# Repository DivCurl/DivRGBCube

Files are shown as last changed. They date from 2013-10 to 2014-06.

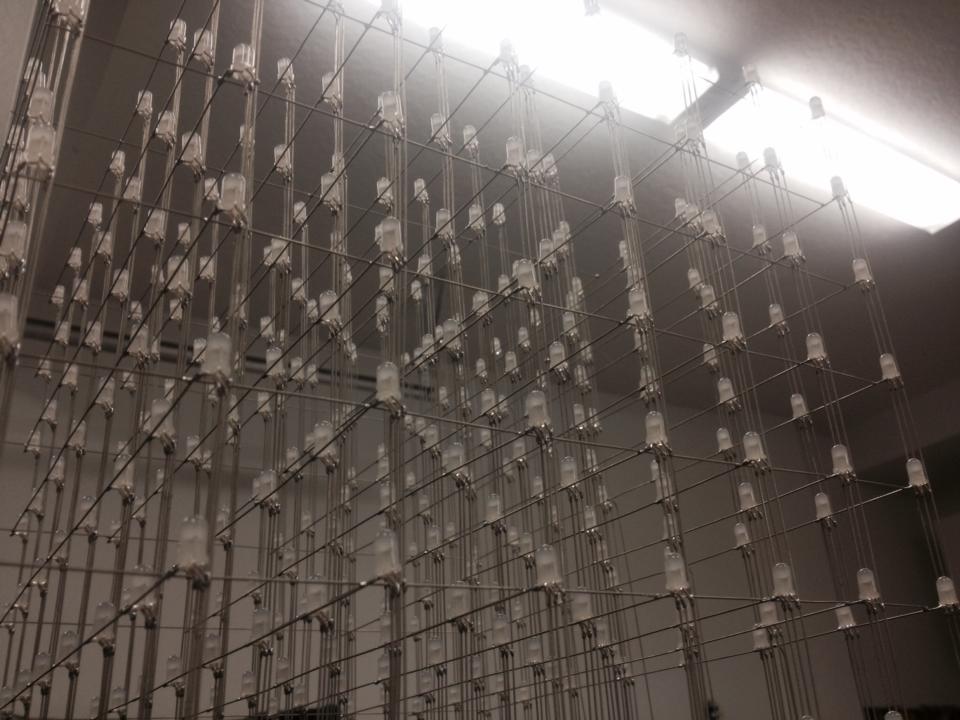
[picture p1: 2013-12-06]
Pics/Post-1.jpg

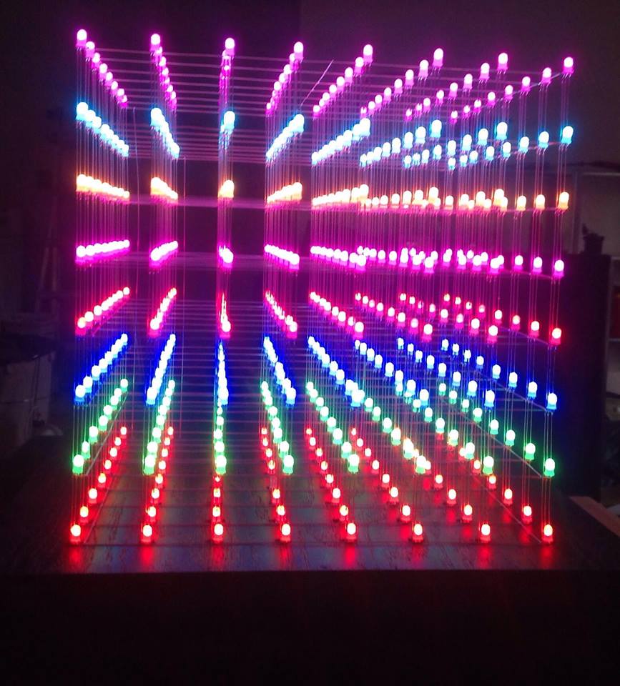
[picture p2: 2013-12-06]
Pics/Cube-4.jpg

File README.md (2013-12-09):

DivRGBCube
==========

8x8x8 RGB Cube Project Resources

Aiming to supply other makers with resources to build my 8^3 RGB LED cube design. Some of the design choices were inspired by others and have been credited appropriately, but this is mostly my own custom design and built completely from scratch. I've provided a custom board layout designed in eagle, which has some minor flaws (nothing I would consider a fault however) which I've noted accordingly, but otherwise I'm using the as-designed board and have yet to encounter a problem. I've also written the software to satisfy my own needs and knowledge level.

All code is written in standard C using Microchip's MPLAB X IDE. I am not a seasoned C veteran by any means so please feel free to suggest alternative or more efficient ways of doing things, I am sure there are plenty of areas which could use some improving and optimization. All build files are included in addition to the source.

The target microcontroller platform is a PIC32. There should be only minimal hassles to port the code to other platforms - I believe the only major portion that would require rewrites would be the interrupt handlers and of course the I/O pin definitions and latch functions (for example the TRIS and LATx macros). The PIC32 was chosen due to its fast speed given that I'm using shift registers for each LED cathode and handling the color fading in software using BCM (aka BAM) thus requiring a very fast refresh rate to avoid flickering artifacts and to maintain a good frame rate. Credits to Nick Schulze of www.hownottoengineer.com for this particular design inspiration. The implementation of software BCM was a fun challenge.

This is still a work in progress project so I'm constantly adding new features so stay tuned for new builds and updates.

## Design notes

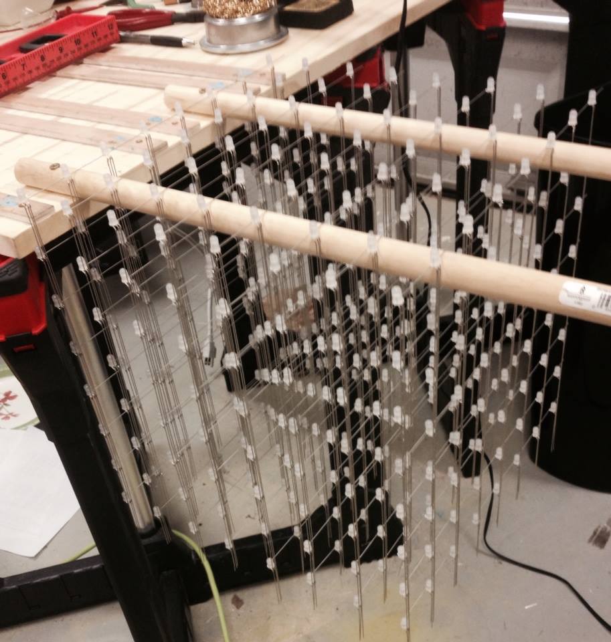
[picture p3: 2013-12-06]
Pics/Cube-1.jpg

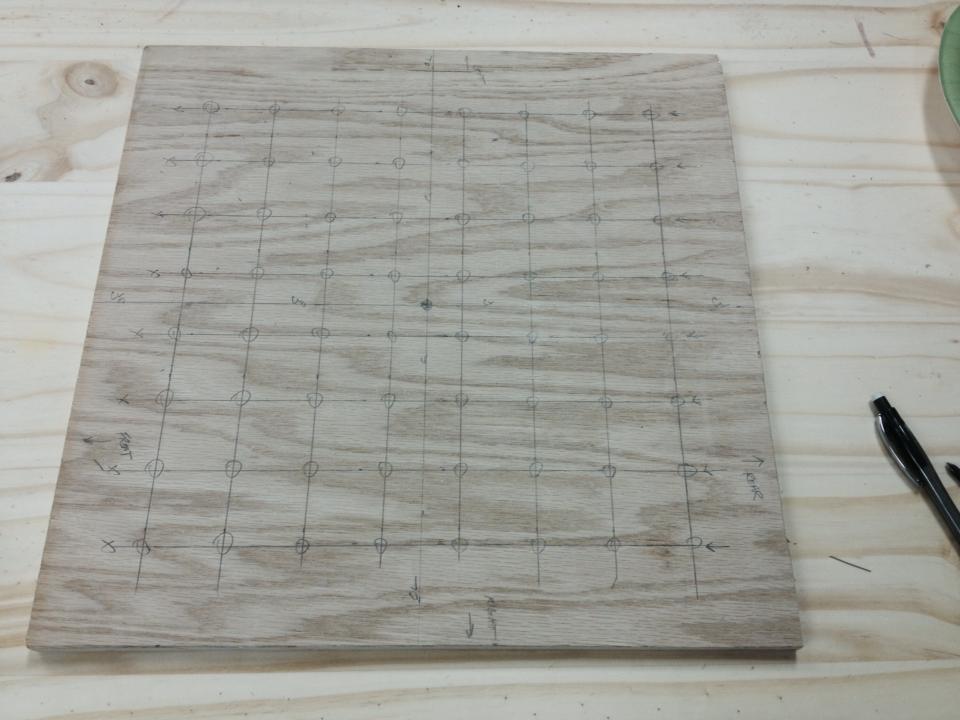
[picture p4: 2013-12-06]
Pics/Box-1.jpg

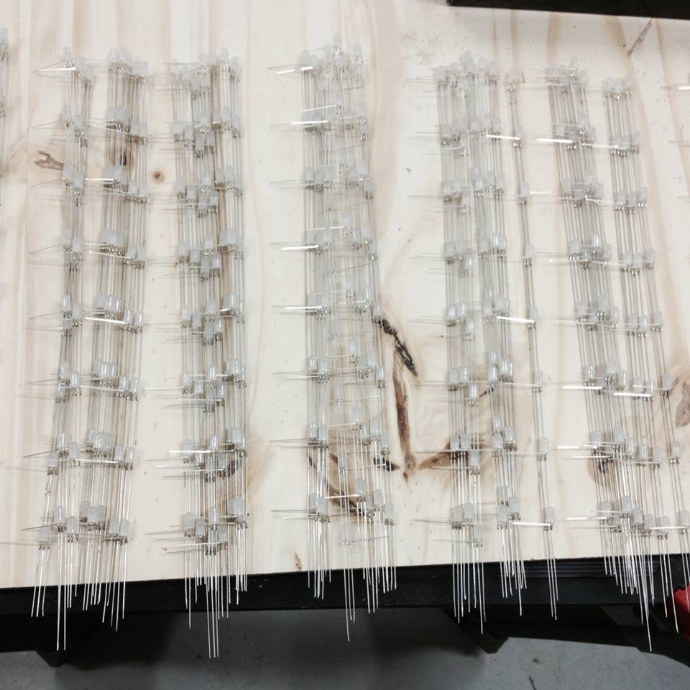
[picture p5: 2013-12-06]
Pics/Jig-7.jpg

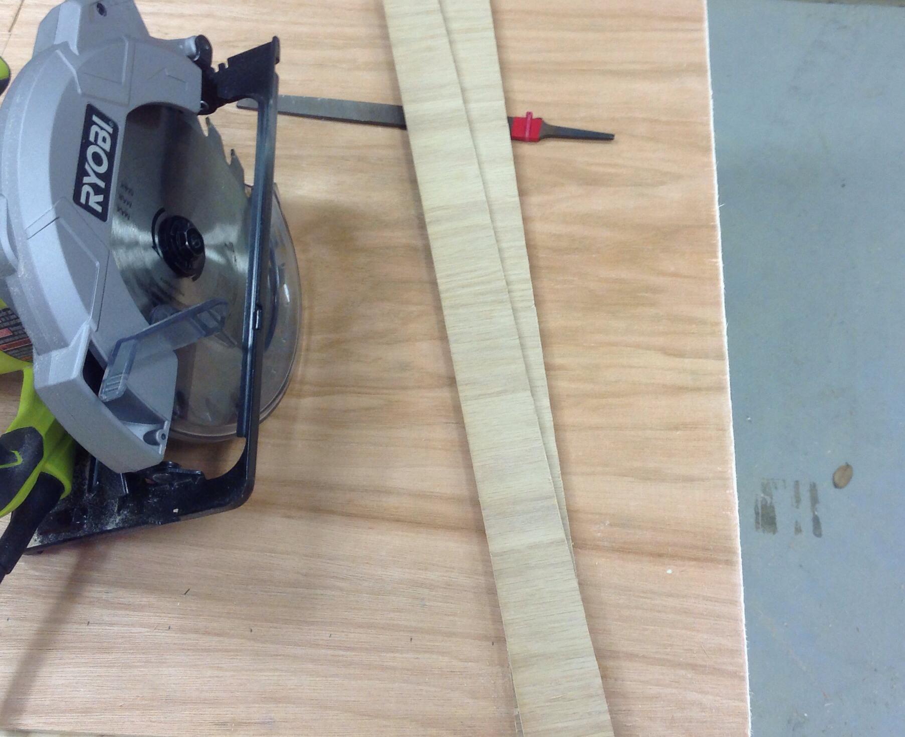
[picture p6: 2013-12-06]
Pics/Jig-1.jpg

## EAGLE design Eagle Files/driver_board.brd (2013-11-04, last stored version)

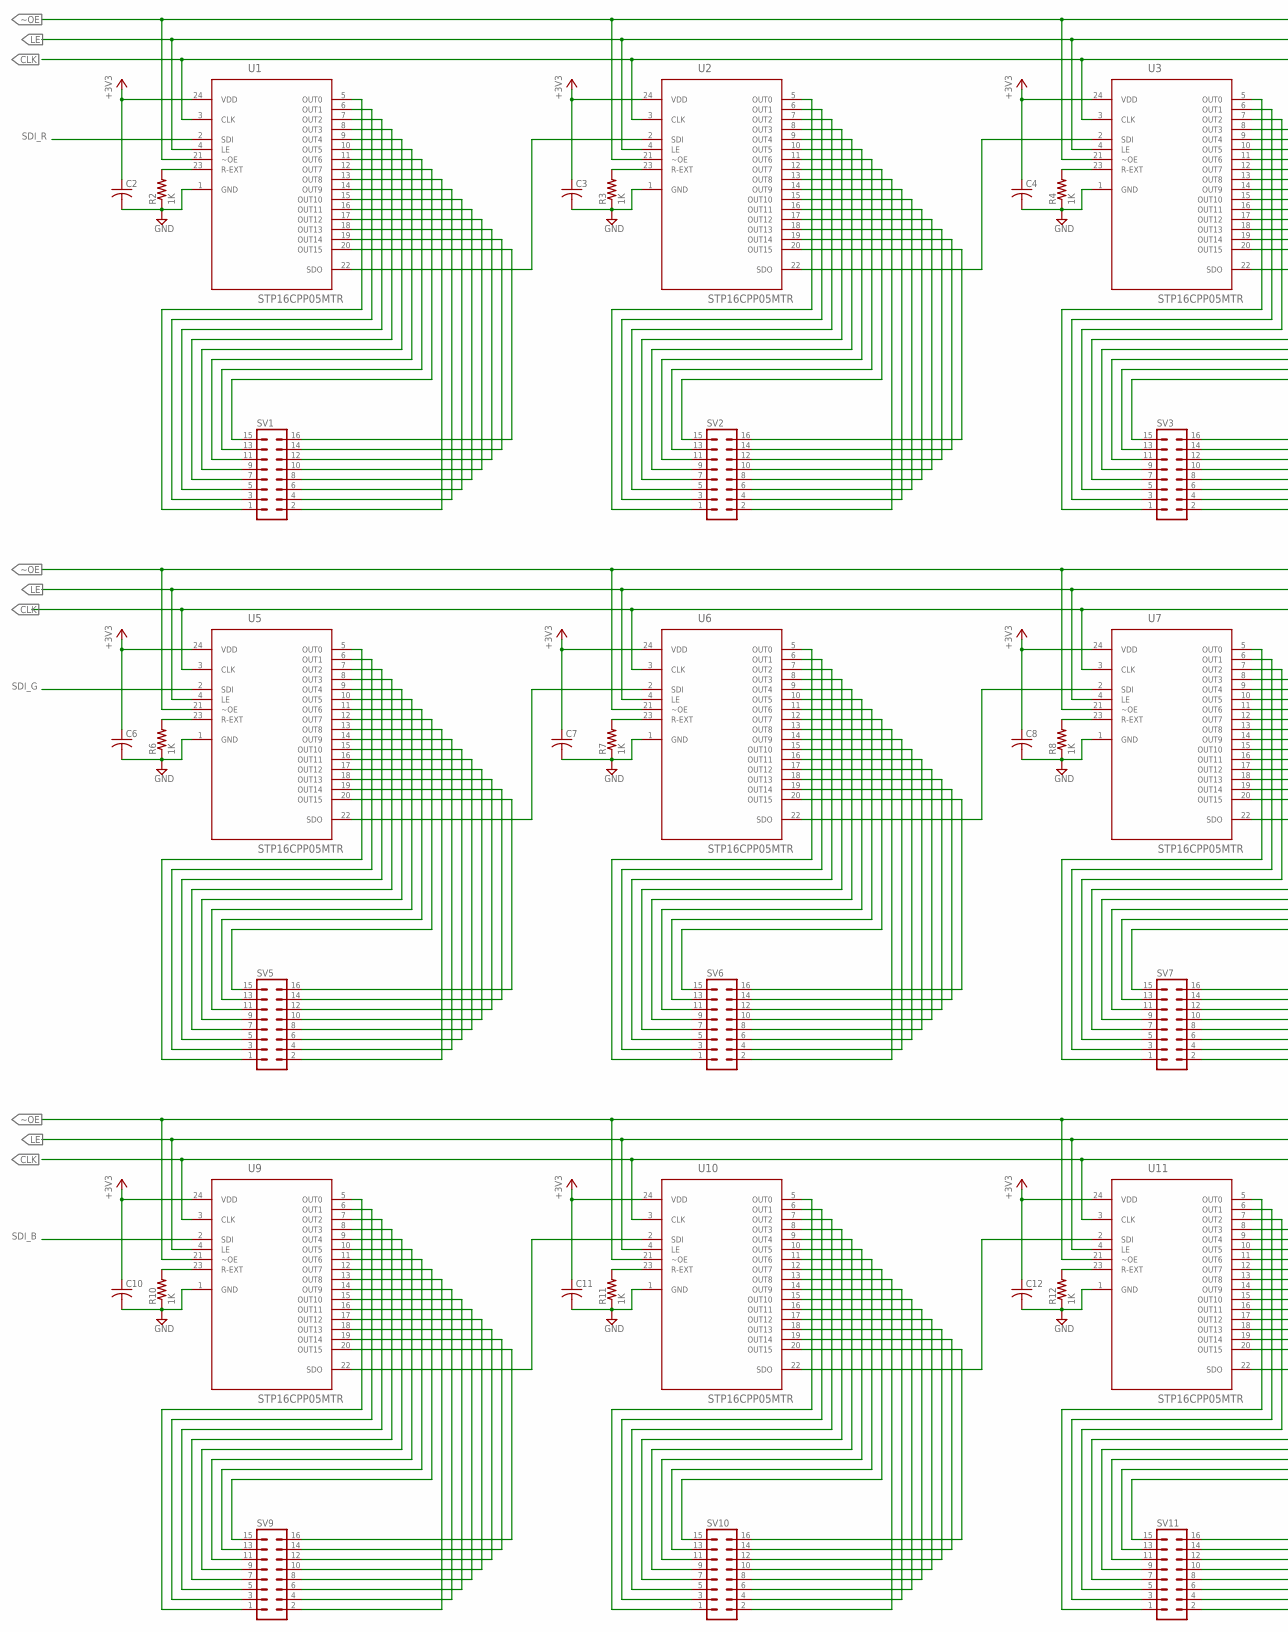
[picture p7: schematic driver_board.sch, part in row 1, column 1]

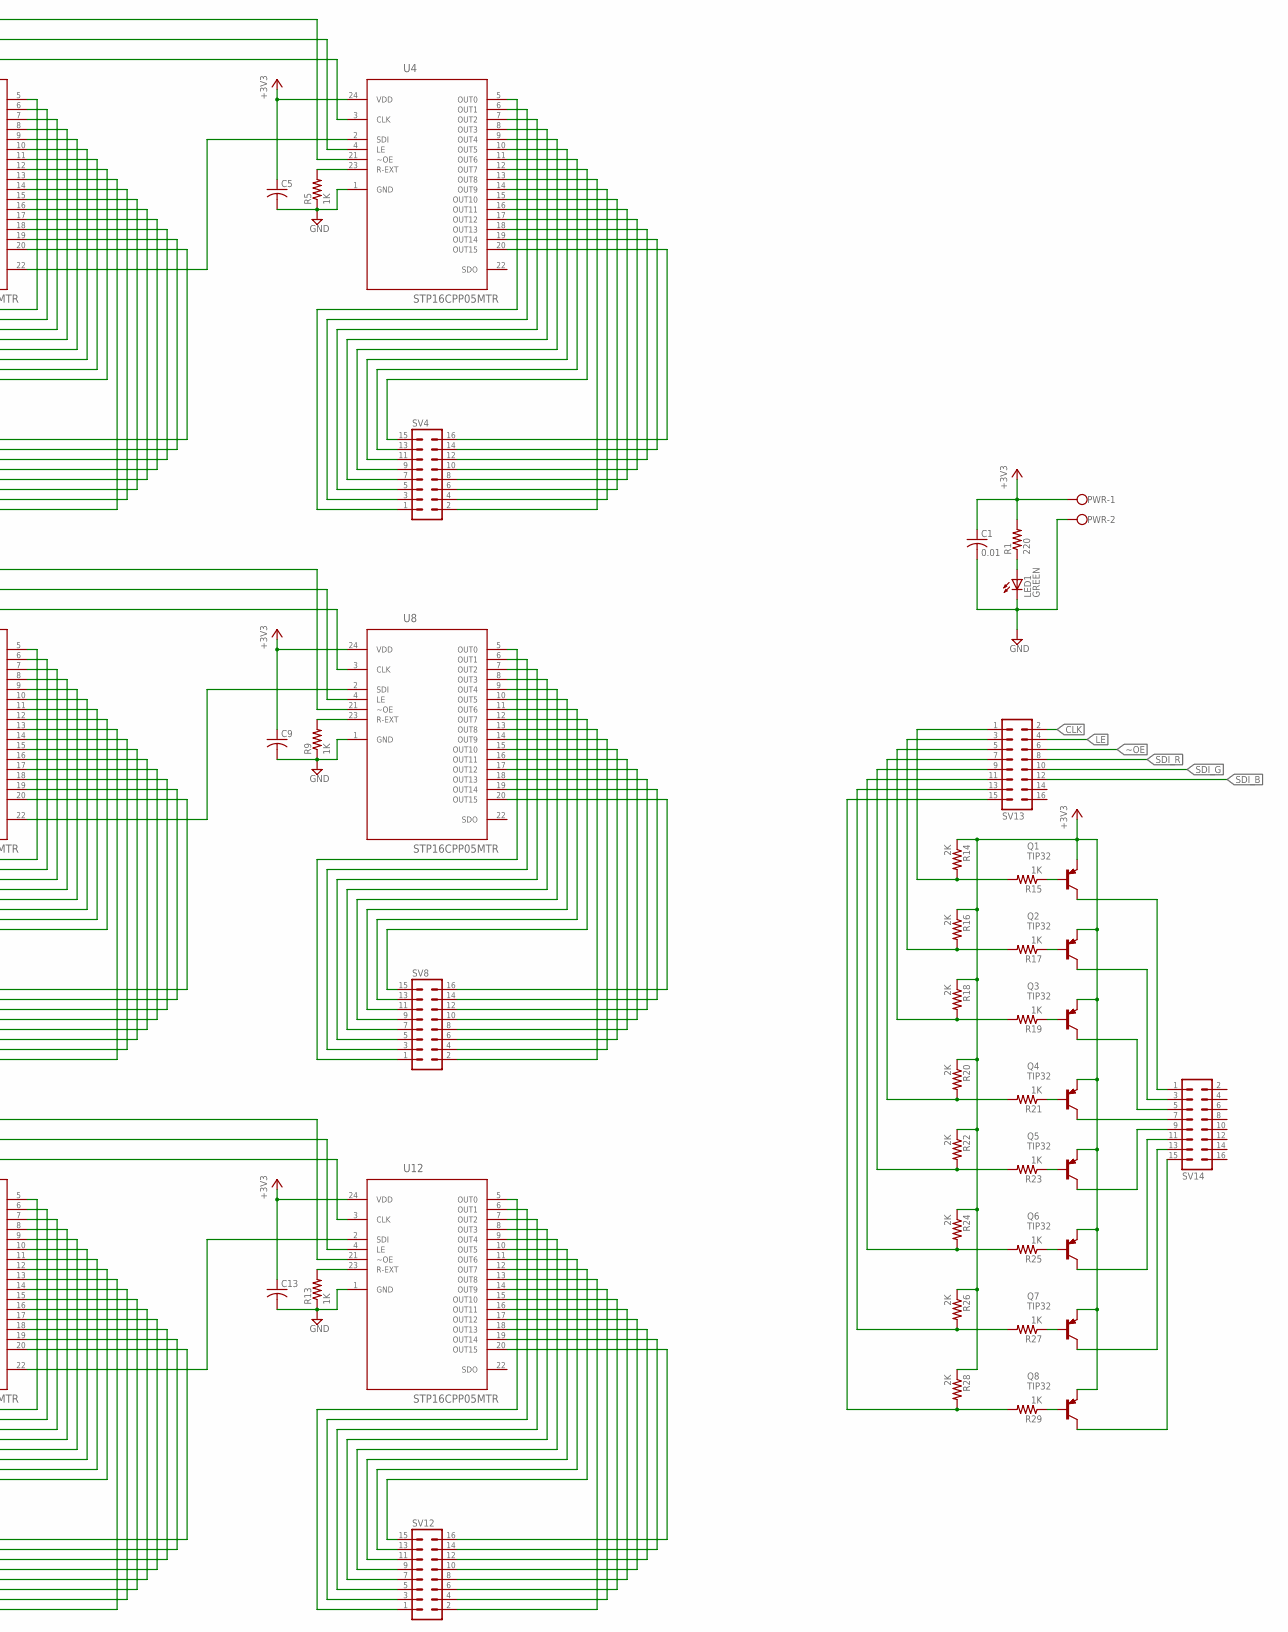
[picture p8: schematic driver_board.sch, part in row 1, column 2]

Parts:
C1: 0.01; C0805; MPN MCCA001261
C2, C3, C4, C5, C6, C7, C8, C9, C10, C11, C12, C13: C-USC0805; C0805; MPN MCCA001261
LED1: GREEN; LED5MM; MPN CMD17-21VGD/TR8
PWR: W237-102
Q1, Q2, Q3, Q4, Q5, Q6, Q7, Q8: TIP32; TO220AV; MPN TIP32BG
R1: 220; R0805; MPN MCHP05W4F2200T5E
R2, R3, R4, R5, R6, R7, R8, R9, R10, R11, R12, R13: 1K; R0805; MPN MC01W080511K
R14, R16, R18, R20, R22, R24, R26, R28: 2K; R0805
R15, R17, R19, R21, R23, R25, R27, R29: 1K; R0805
SV1, SV2, SV3, SV4, SV5, SV6, SV7, SV8, SV9, SV10, SV11, SV12, SV13, SV14: 16PL; MPN 008380016000010
U1, U2, U3, U4, U5, U6, U7, U8, U9, U10, U11, U12: STP16CPP05MTR; SOIC127P1032X265-24N

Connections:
+3V3: C1.1, C2.1, C3.1, C4.1, C5.1, C6.1, C7.1, C8.1, C9.1, C10.1, C11.1, C12.1, C13.1, PWR.1, Q1.E, Q2.E, Q3.E, Q4.E, Q5.E, Q6.E, Q7.E, Q8.E, R1.2, R14.1, R16.1, R18.1, R20.1, R22.1, R24.1, R26.1, R28.1, U1.24 (VDD), U2.24 (VDD), U3.24 (VDD), U4.24 (VDD), U5.24 (VDD), U6.24 (VDD), U7.24 (VDD), U8.24 (VDD), U9.24 (VDD), U10.24 (VDD), U11.24 (VDD), U12.24 (VDD)
CLK: SV13.2, U1.3 (CLK), U2.3 (CLK), U3.3 (CLK), U4.3 (CLK), U5.3 (CLK), U6.3 (CLK), U7.3 (CLK), U8.3 (CLK), U9.3 (CLK), U10.3 (CLK), U11.3 (CLK), U12.3 (CLK)
GND: C1.2, C2.2, C3.2, C4.2, C5.2, C6.2, C7.2, C8.2, C9.2, C10.2, C11.2, C12.2, C13.2, LED1.K (C), PWR.2, R2.1, R3.1, R4.1, R5.1, R6.1, R7.1, R8.1, R9.1, R10.1, R11.1, R12.1, R13.1, U1.1 (GND), U2.1 (GND), U3.1 (GND), U4.1 (GND), U5.1 (GND), U6.1 (GND), U7.1 (GND), U8.1 (GND), U9.1 (GND), U10.1 (GND), U11.1 (GND), U12.1 (GND)
LE: SV13.4, U1.4 (LE), U2.4 (LE), U3.4 (LE), U4.4 (LE), U5.4 (LE), U6.4 (LE), U7.4 (LE), U8.4 (LE), U9.4 (LE), U10.4 (LE), U11.4 (LE), U12.4 (LE)
unnamed: SV1.1, U1.5 (OUT0)
unnamed: SV1.5, U1.7 (OUT2)
unnamed: SV1.3, U1.6 (OUT1)
unnamed: SV1.7, U1.8 (OUT3)
unnamed: SV1.11, U1.10 (OUT5)
unnamed: SV1.13, U1.11 (OUT6)
unnamed: SV1.9, U1.9 (OUT4)
unnamed: SV1.15, U1.12 (OUT7)
unnamed: SV1.2, U1.13 (OUT8)
unnamed: SV1.4, U1.14 (OUT9)
unnamed: SV1.6, U1.15 (OUT10)
unnamed: SV1.8, U1.16 (OUT11)
unnamed: SV1.10, U1.17 (OUT12)
unnamed: SV1.12, U1.18 (OUT13)
unnamed: SV1.14, U1.19 (OUT14)
unnamed: SV1.16, U1.20 (OUT15)
unnamed: SV8.2, U8.13 (OUT8)
unnamed: R2.2, U1.23 (R-EXT)
unnamed: SV8.4, U8.14 (OUT9)
unnamed: SV8.8, U8.16 (OUT11)
unnamed: SV8.6, U8.15 (OUT10)
unnamed: SV8.10, U8.17 (OUT12)
unnamed: SV8.12, U8.18 (OUT13)
unnamed: SV8.14, U8.19 (OUT14)
unnamed: SV8.16, U8.20 (OUT15)
unnamed: SV2.1, U2.5 (OUT0)
unnamed: SV2.3, U2.6 (OUT1)
unnamed: SV2.5, U2.7 (OUT2)
unnamed: SV2.7, U2.8 (OUT3)
unnamed: SV2.11, U2.10 (OUT5)
unnamed: SV2.9, U2.9 (OUT4)
unnamed: SV2.13, U2.11 (OUT6)
unnamed: SV2.15, U2.12 (OUT7)
unnamed: R3.2, U2.23 (R-EXT)
unnamed: SV5.1, U5.5 (OUT0)
unnamed: SV5.3, U5.6 (OUT1)
unnamed: SV5.5, U5.7 (OUT2)
unnamed: SV5.7, U5.8 (OUT3)
unnamed: SV5.11, U5.10 (OUT5)
unnamed: SV5.9, U5.9 (OUT4)
unnamed: SV5.13, U5.11 (OUT6)
unnamed: SV5.15, U5.12 (OUT7)
unnamed: SV5.2, U5.13 (OUT8)
unnamed: SV5.4, U5.14 (OUT9)
unnamed: SV5.6, U5.15 (OUT10)
unnamed: SV5.8, U5.16 (OUT11)
unnamed: SV5.10, U5.17 (OUT12)
unnamed: SV5.12, U5.18 (OUT13)
unnamed: SV5.14, U5.19 (OUT14)
unnamed: SV5.16, U5.20 (OUT15)
unnamed: R4.2, U3.23 (R-EXT)
unnamed: SV6.1, U6.5 (OUT0)
unnamed: SV6.3, U6.6 (OUT1)
unnamed: SV6.5, U6.7 (OUT2)
unnamed: SV6.7, U6.8 (OUT3)
unnamed: SV6.11, U6.10 (OUT5)
unnamed: SV6.9, U6.9 (OUT4)
unnamed: SV6.13, U6.11 (OUT6)
unnamed: SV6.15, U6.12 (OUT7)
unnamed: SV6.2, U6.13 (OUT8)
unnamed: SV6.4, U6.14 (OUT9)
unnamed: SV6.6, U6.15 (OUT10)
unnamed: SV6.8, U6.16 (OUT11)
unnamed: SV6.10, U6.17 (OUT12)
unnamed: SV6.12, U6.18 (OUT13)
unnamed: SV6.14, U6.19 (OUT14)
unnamed: SV6.16, U6.20 (OUT15)
unnamed: R5.2, U4.23 (R-EXT)
unnamed: SV7.1, U7.5 (OUT0)
unnamed: SV7.3, U7.6 (OUT1)
unnamed: SV7.5, U7.7 (OUT2)
unnamed: SV7.7, U7.8 (OUT3)
unnamed: SV7.11, U7.10 (OUT5)
unnamed: SV7.9, U7.9 (OUT4)
unnamed: SV7.13, U7.11 (OUT6)
unnamed: SV7.15, U7.12 (OUT7)
unnamed: SV7.2, U7.13 (OUT8)
unnamed: SV7.4, U7.14 (OUT9)
unnamed: SV7.6, U7.15 (OUT10)
unnamed: SV7.8, U7.16 (OUT11)
unnamed: SV7.10, U7.17 (OUT12)
unnamed: SV7.12, U7.18 (OUT13)
unnamed: SV7.14, U7.19 (OUT14)
unnamed: SV7.16, U7.20 (OUT15)
unnamed: R6.2, U5.23 (R-EXT)
unnamed: SV8.1, U8.5 (OUT0)
unnamed: SV8.3, U8.6 (OUT1)
unnamed: SV8.5, U8.7 (OUT2)
unnamed: SV8.7, U8.8 (OUT3)
unnamed: SV8.11, U8.10 (OUT5)
unnamed: SV8.9, U8.9 (OUT4)
unnamed: SV8.13, U8.11 (OUT6)
unnamed: SV8.15, U8.12 (OUT7)
unnamed: SV2.2, U2.13 (OUT8)
unnamed: SV2.4, U2.14 (OUT9)
unnamed: SV2.6, U2.15 (OUT10)
unnamed: SV2.8, U2.16 (OUT11)
unnamed: SV2.12, U2.18 (OUT13)
unnamed: SV2.14, U2.19 (OUT14)
unnamed: SV2.16, U2.20 (OUT15)
unnamed: SV2.10, U2.17 (OUT12)
unnamed: SV3.1, U3.5 (OUT0)
unnamed: R7.2, U6.23 (R-EXT)
unnamed: SV3.3, U3.6 (OUT1)
unnamed: SV3.5, U3.7 (OUT2)
unnamed: SV3.7, U3.8 (OUT3)
unnamed: SV3.9, U3.9 (OUT4)
unnamed: SV3.11, U3.10 (OUT5)
unnamed: SV3.13, U3.11 (OUT6)
unnamed: SV3.15, U3.12 (OUT7)
unnamed: SV3.2, U3.13 (OUT8)
unnamed: SV3.4, U3.14 (OUT9)
unnamed: SV3.6, U3.15 (OUT10)
unnamed: SV3.8, U3.16 (OUT11)
unnamed: SV3.10, U3.17 (OUT12)
unnamed: SV3.12, U3.18 (OUT13)
unnamed: SV3.14, U3.19 (OUT14)
unnamed: SV3.16, U3.20 (OUT15)
unnamed: R8.2, U7.23 (R-EXT)
unnamed: SV4.1, U4.5 (OUT0)
unnamed: SV4.3, U4.6 (OUT1)
unnamed: R9.2, U8.23 (R-EXT)
unnamed: SV4.5, U4.7 (OUT2)
unnamed: SV4.7, U4.8 (OUT3)
unnamed: SV4.11, U4.10 (OUT5)
unnamed: SV4.9, U4.9 (OUT4)
unnamed: SV4.13, U4.11 (OUT6)
unnamed: SV4.15, U4.12 (OUT7)
unnamed: SV4.2, U4.13 (OUT8)
unnamed: SV4.4, U4.14 (OUT9)
unnamed: SV4.6, U4.15 (OUT10)
unnamed: SV4.8, U4.16 (OUT11)
unnamed: SV4.10, U4.17 (OUT12)
unnamed: SV4.12, U4.18 (OUT13)
unnamed: SV4.14, U4.19 (OUT14)
unnamed: SV4.16, U4.20 (OUT15)
unnamed: SV9.1, U9.5 (OUT0)
unnamed: SV9.3, U9.6 (OUT1)
unnamed: SV9.5, U9.7 (OUT2)
unnamed: R10.2, U9.23 (R-EXT)
unnamed: SV9.7, U9.8 (OUT3)
unnamed: SV9.11, U9.10 (OUT5)
unnamed: SV9.9, U9.9 (OUT4)
unnamed: SV9.13, U9.11 (OUT6)
unnamed: SV9.15, U9.12 (OUT7)
unnamed: SV9.2, U9.13 (OUT8)
unnamed: SV9.4, U9.14 (OUT9)
unnamed: SV9.6, U9.15 (OUT10)
unnamed: SV9.8, U9.16 (OUT11)
unnamed: SV9.10, U9.17 (OUT12)
unnamed: SV9.12, U9.18 (OUT13)
unnamed: SV9.14, U9.19 (OUT14)
unnamed: SV9.16, U9.20 (OUT15)
unnamed: SV10.1, U10.5 (OUT0)
unnamed: SV10.3, U10.6 (OUT1)
unnamed: SV10.5, U10.7 (OUT2)
unnamed: R11.2, U10.23 (R-EXT)
unnamed: SV10.7, U10.8 (OUT3)
unnamed: SV10.11, U10.10 (OUT5)
unnamed: SV10.9, U10.9 (OUT4)
unnamed: SV10.13, U10.11 (OUT6)
unnamed: SV10.15, U10.12 (OUT7)
unnamed: SV10.2, U10.13 (OUT8)
unnamed: SV10.4, U10.14 (OUT9)
unnamed: SV10.6, U10.15 (OUT10)
unnamed: SV10.8, U10.16 (OUT11)
unnamed: SV10.10, U10.17 (OUT12)
unnamed: SV10.12, U10.18 (OUT13)
unnamed: SV10.14, U10.19 (OUT14)
unnamed: SV10.16, U10.20 (OUT15)
unnamed: SV11.1, U11.5 (OUT0)
unnamed: SV11.3, U11.6 (OUT1)
unnamed: SV11.5, U11.7 (OUT2)
unnamed: SV11.7, U11.8 (OUT3)
unnamed: R12.2, U11.23 (R-EXT)
unnamed: SV11.11, U11.10 (OUT5)
unnamed: SV11.9, U11.9 (OUT4)
unnamed: SV11.13, U11.11 (OUT6)
unnamed: SV11.15, U11.12 (OUT7)
unnamed: SV11.2, U11.13 (OUT8)
unnamed: SV11.4, U11.14 (OUT9)
unnamed: SV11.6, U11.15 (OUT10)
unnamed: SV11.8, U11.16 (OUT11)
unnamed: SV11.10, U11.17 (OUT12)
unnamed: SV11.12, U11.18 (OUT13)
unnamed: SV11.14, U11.19 (OUT14)
unnamed: SV11.16, U11.20 (OUT15)
unnamed: SV12.1, U12.5 (OUT0)
unnamed: SV12.3, U12.6 (OUT1)
unnamed: SV12.5, U12.7 (OUT2)
unnamed: SV12.7, U12.8 (OUT3)
unnamed: SV12.11, U12.10 (OUT5)
unnamed: R13.2, U12.23 (R-EXT)
unnamed: U1.22 (SDO), U2.2 (SDI)
unnamed: U2.22 (SDO), U3.2 (SDI)
unnamed: U3.22 (SDO), U4.2 (SDI)
unnamed: U5.22 (SDO), U6.2 (SDI)
unnamed: U6.22 (SDO), U7.2 (SDI)
unnamed: U7.22 (SDO), U8.2 (SDI)
unnamed: U9.22 (SDO), U10.2 (SDI)
unnamed: U10.22 (SDO), U11.2 (SDI)
unnamed: U11.22 (SDO), U12.2 (SDI)
unnamed: Q1.C, SV14.1
unnamed: Q2.C, SV14.3
unnamed: Q3.C, SV14.5
unnamed: Q4.C, SV14.7
unnamed: Q5.C, SV14.9
unnamed: Q6.C, SV14.11
unnamed: Q1.B, R15.1
unnamed: Q7.C, SV14.13
unnamed: Q8.C, SV14.15
unnamed: Q8.B, R29.1
unnamed: Q7.B, R27.1
unnamed: Q6.B, R25.1
unnamed: Q5.B, R23.1
unnamed: Q4.B, R21.1
unnamed: Q3.B, R19.1
unnamed: Q2.B, R17.1
unnamed: SV12.9, U12.9 (OUT4)
unnamed: R28.2, R29.2, SV13.15
unnamed: LED1.A, R1.1
unnamed: R26.2, R27.2, SV13.13
unnamed: R24.2, R25.2, SV13.11
unnamed: R22.2, R23.2, SV13.9
unnamed: R20.2, R21.2, SV13.7
unnamed: R18.2, R19.2, SV13.5
unnamed: R16.2, R17.2, SV13.3
unnamed: R14.2, R15.2, SV13.1
unnamed: SV12.13, U12.11 (OUT6)
unnamed: SV12.15, U12.12 (OUT7)
unnamed: SV12.2, U12.13 (OUT8)
unnamed: SV12.4, U12.14 (OUT9)
unnamed: SV12.6, U12.15 (OUT10)
unnamed: SV12.8, U12.16 (OUT11)
unnamed: SV12.10, U12.17 (OUT12)
unnamed: SV12.12, U12.18 (OUT13)
unnamed: SV12.14, U12.19 (OUT14)
unnamed: SV12.16, U12.20 (OUT15)
SDI_B: SV13.12, U9.2 (SDI)
SDI_G: SV13.10, U5.2 (SDI)
SDI_R: SV13.8, U1.2 (SDI)
~OE: SV13.6, U1.21 (~OE), U2.21 (~OE), U3.21 (~OE), U4.21 (~OE), U5.21 (~OE), U6.21 (~OE), U7.21 (~OE), U8.21 (~OE), U9.21 (~OE), U10.21 (~OE), U11.21 (~OE), U12.21 (~OE)

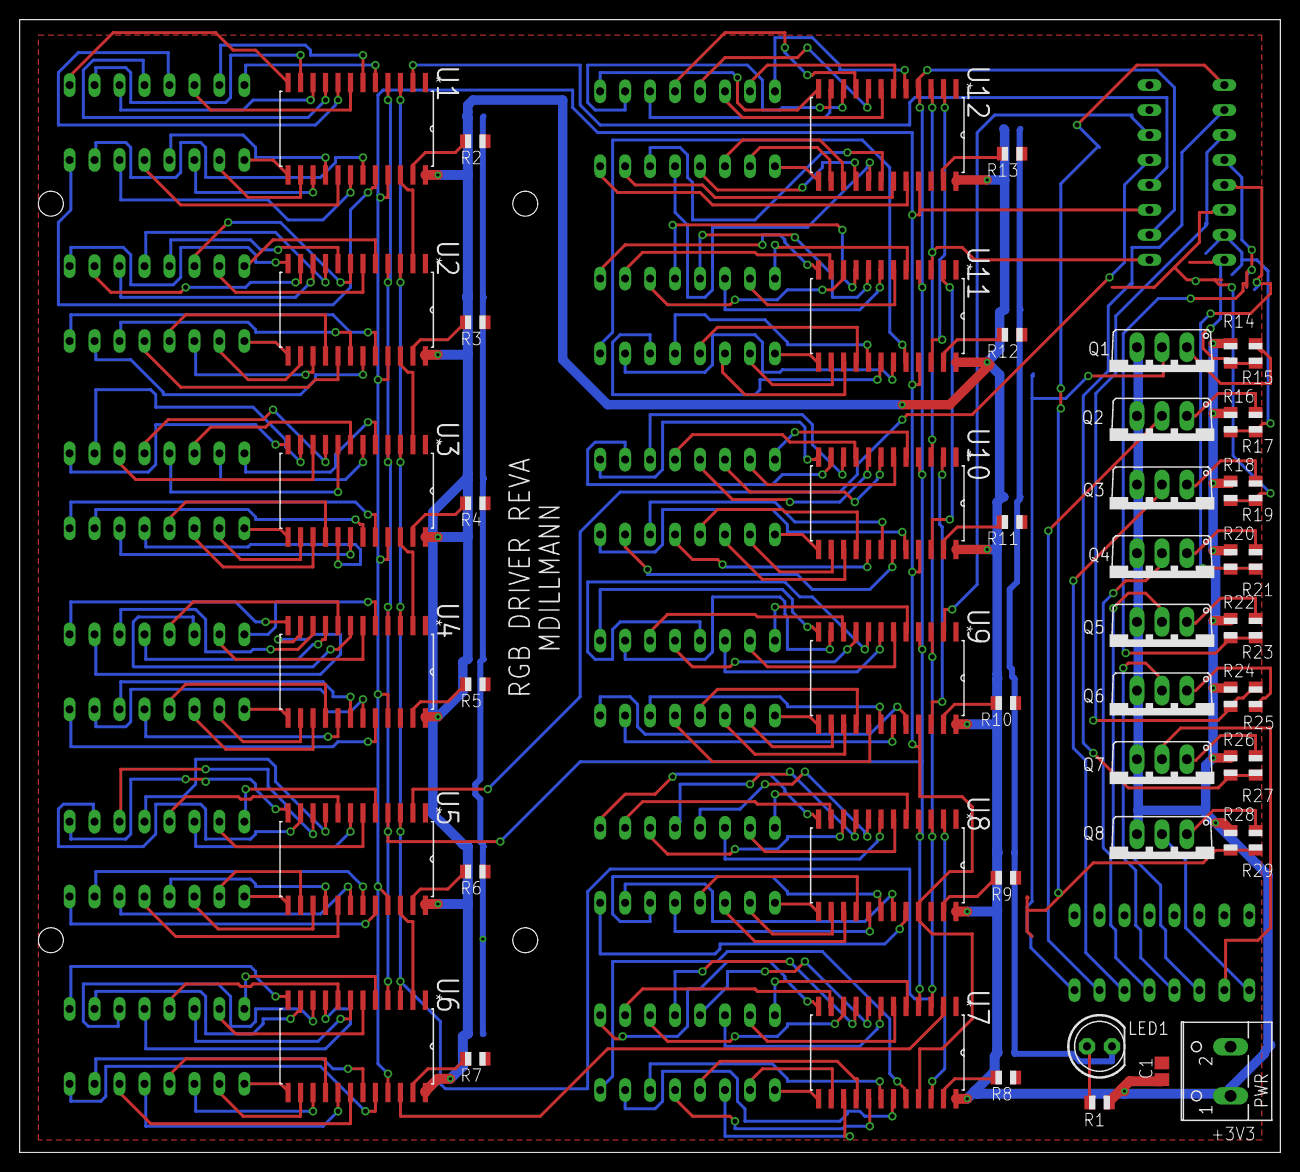
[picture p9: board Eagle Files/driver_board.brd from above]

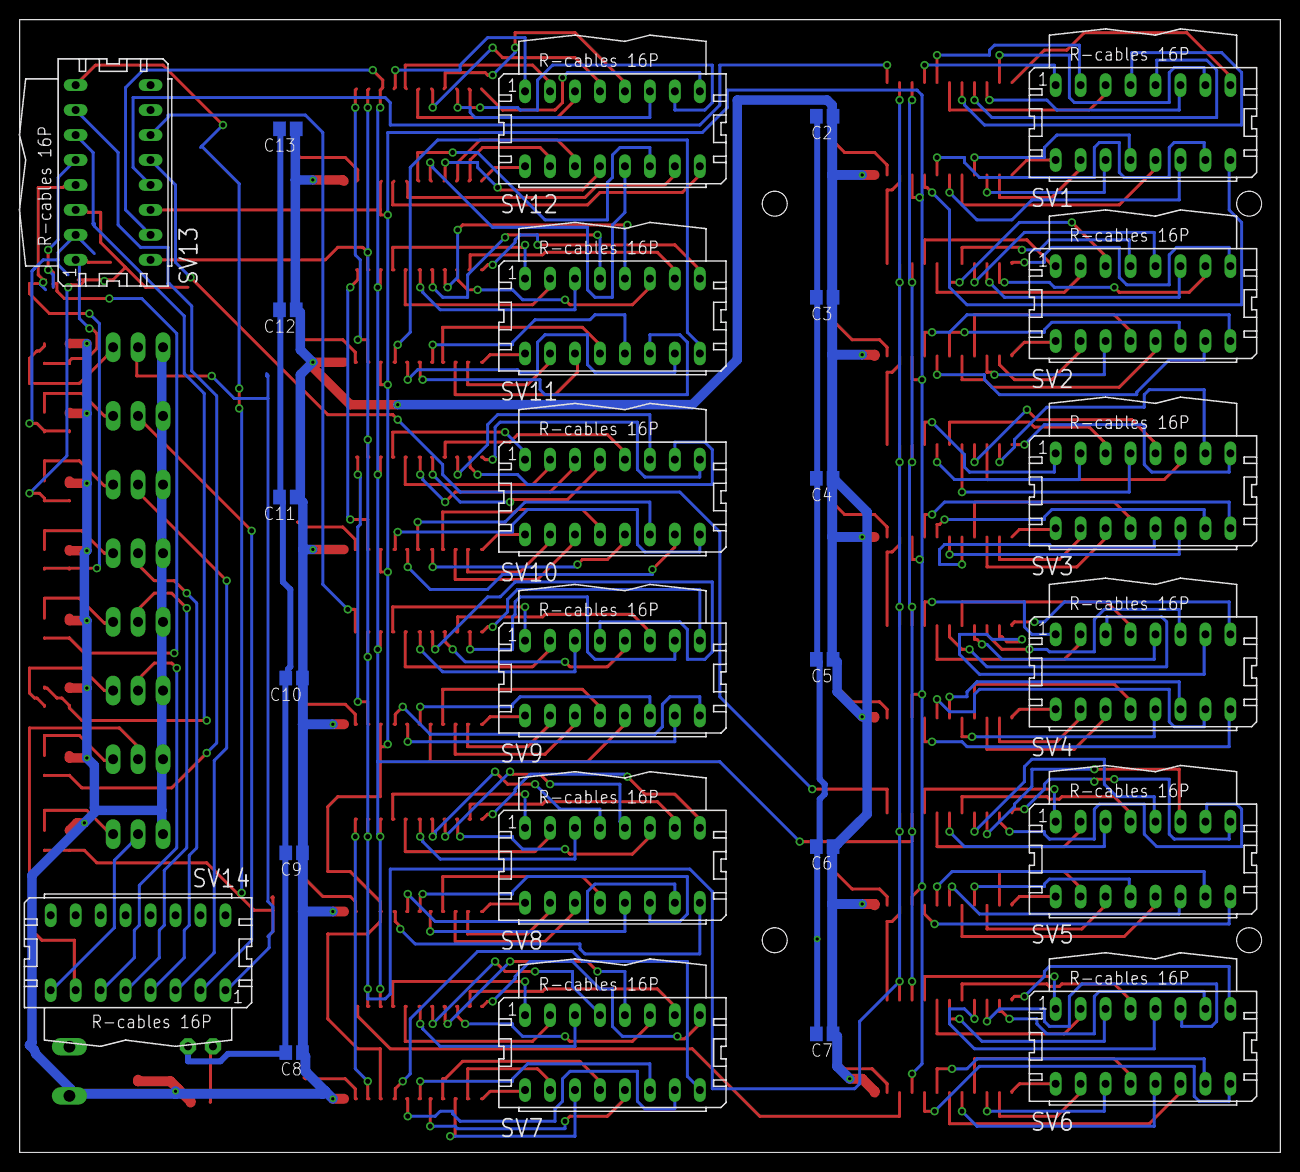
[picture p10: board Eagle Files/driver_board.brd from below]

Board: 2 copper layers, 128.2 x 115.2 mm, 78 parts (26 on the bottom side), 246 nets.

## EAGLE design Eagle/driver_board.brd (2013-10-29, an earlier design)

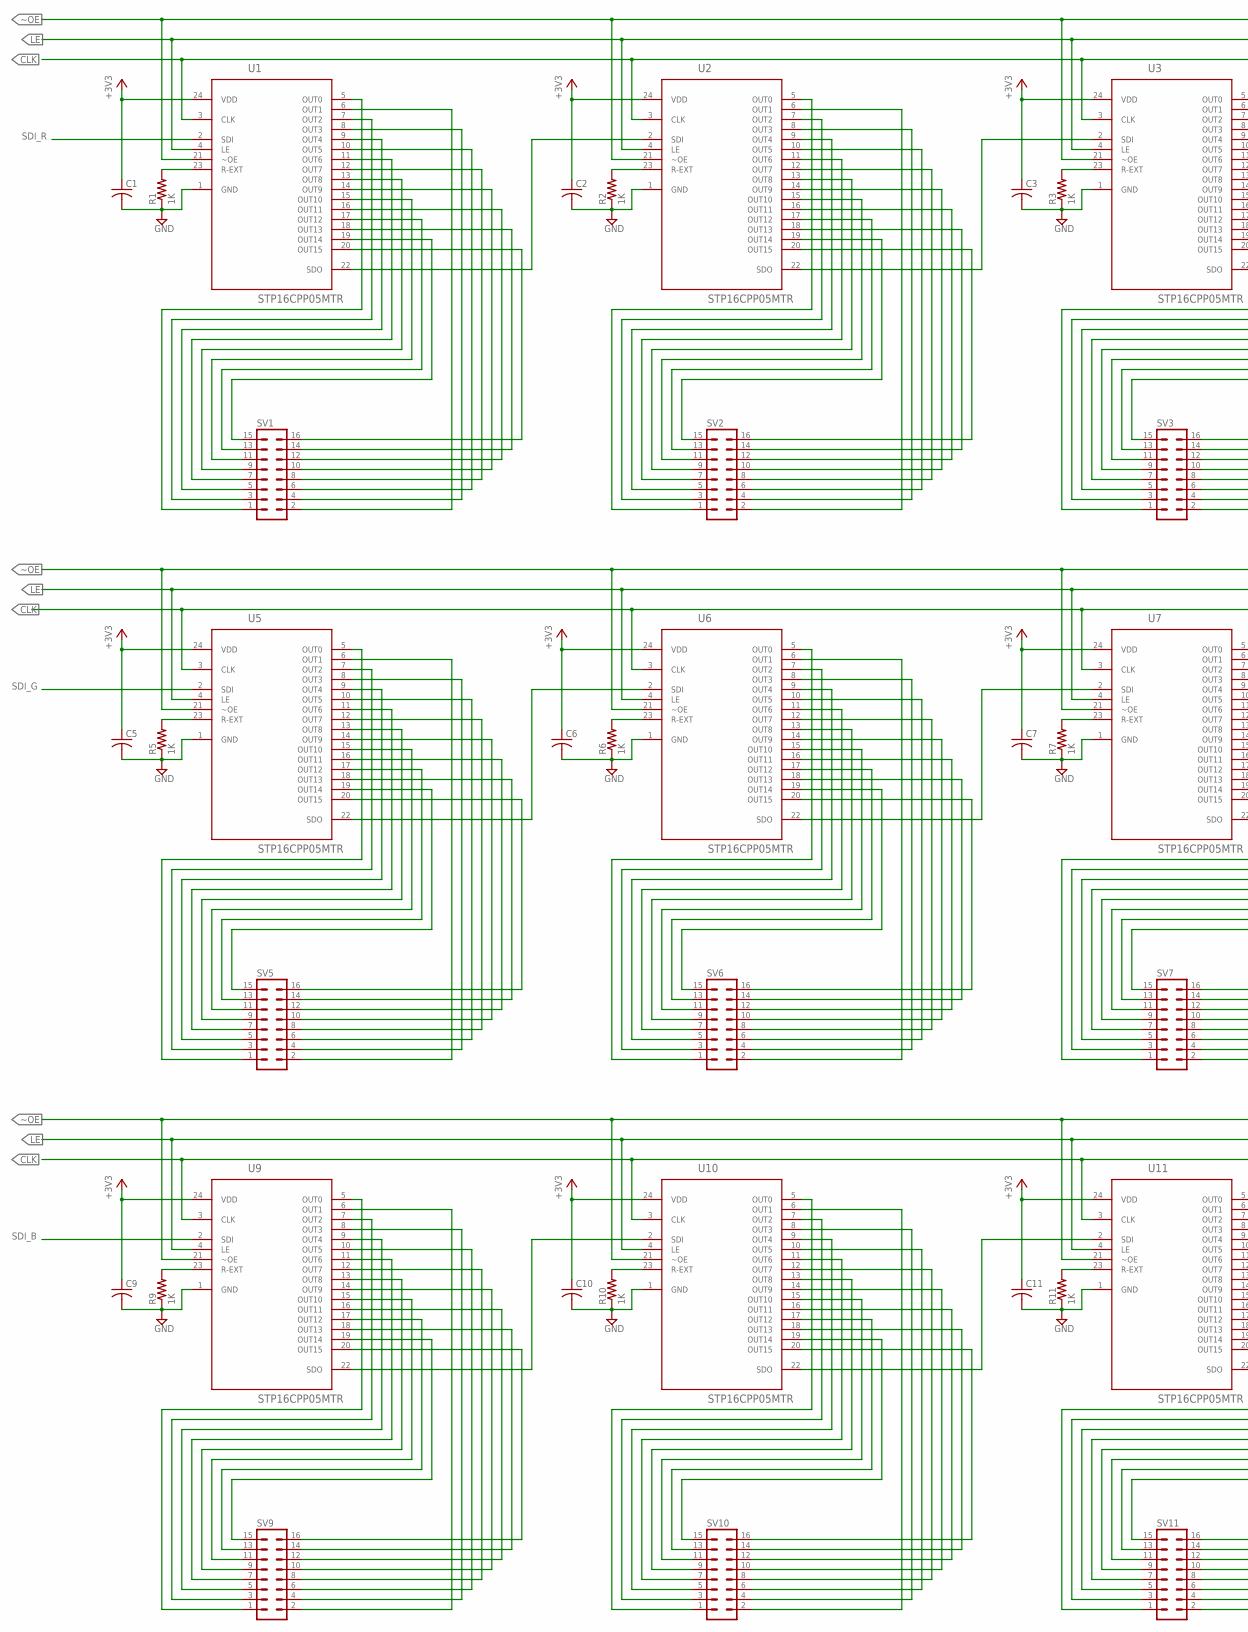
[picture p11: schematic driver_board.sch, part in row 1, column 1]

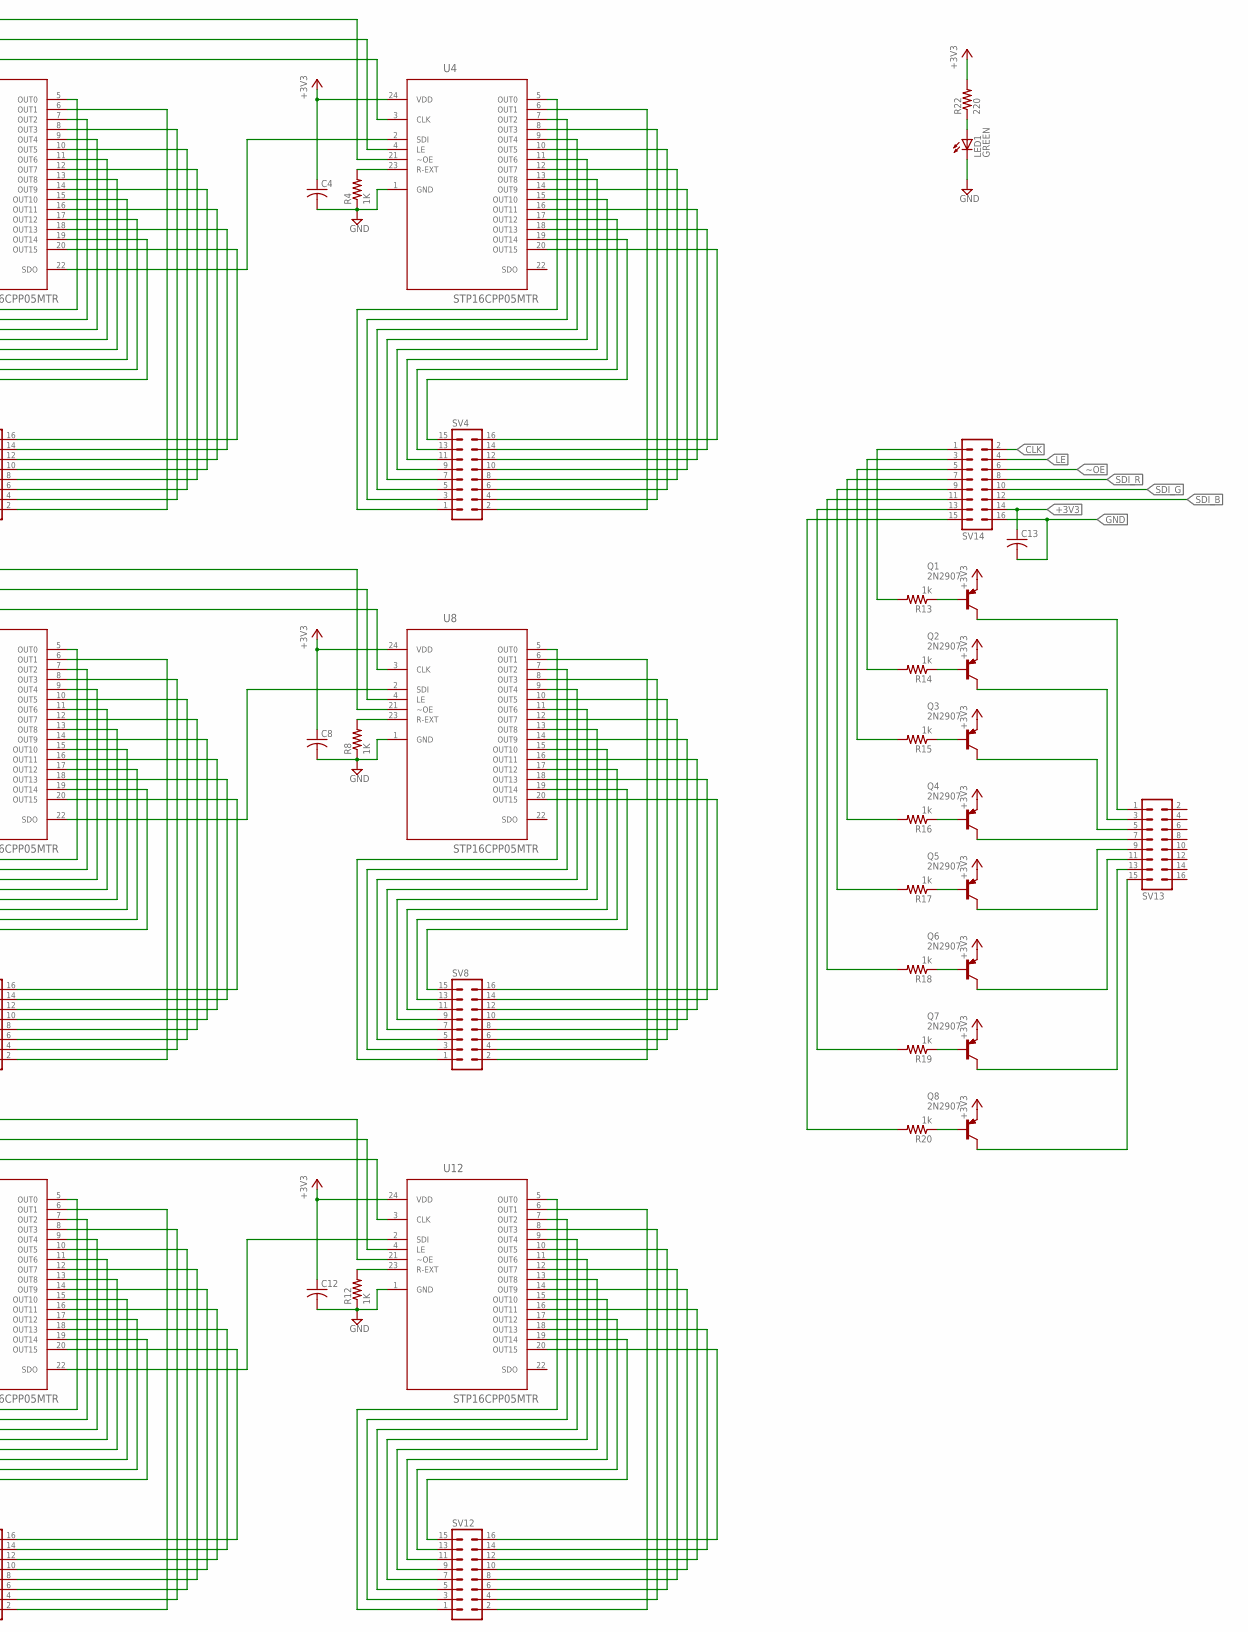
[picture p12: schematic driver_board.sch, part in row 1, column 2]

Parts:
C1, C2, C3, C4, C5, C6, C7, C8, C9, C10, C11, C12, C13: C-USC0805; C0805; MPN 0805ZC105KAT2A
LED1: GREEN; LED5MM; MPN CMD17-21VGD/TR8
Q1, Q2, Q3, Q4, Q5, Q6, Q7, Q8: 2N2907; TO92-EBC-OVAL; MPN TIP32BG
R1, R2, R3, R4, R5, R6, R7, R8, R9, R10, R11, R12: 1K; R0805; MPN MC01W080511K
R13, R14, R15, R16, R17, R18, R19, R20: 1k; R0805
R22: 220; R0805; MPN MCHP05W4F2200T5E
SV1, SV2, SV3, SV4, SV5, SV6, SV7, SV8, SV9, SV10, SV11, SV12, SV13, SV14: 16PL; MPN 008380016000010
U1, U2, U3, U4, U5, U6, U7, U8, U9, U10, U11, U12: STP16CPP05MTR; SOIC127P1032X265-24N

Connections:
+3V3: C1.1, C2.1, C3.1, C4.1, C5.1, C6.1, C7.1, C8.1, C9.1, C10.1, C11.1, C12.1, C13.1, Q1.E, Q2.E, Q3.E, Q4.E, Q5.E, Q6.E, Q7.E, Q8.E, R22.2, SV14.14, U1.24 (VDD), U2.24 (VDD), U3.24 (VDD), U4.24 (VDD), U5.24 (VDD), U6.24 (VDD), U7.24 (VDD), U8.24 (VDD), U9.24 (VDD), U10.24 (VDD), U11.24 (VDD), U12.24 (VDD)
CLK: SV14.2, U1.3 (CLK), U2.3 (CLK), U3.3 (CLK), U4.3 (CLK), U5.3 (CLK), U6.3 (CLK), U7.3 (CLK), U8.3 (CLK), U9.3 (CLK), U10.3 (CLK), U11.3 (CLK), U12.3 (CLK)
GND: C1.2, C2.2, C3.2, C4.2, C5.2, C6.2, C7.2, C8.2, C9.2, C10.2, C11.2, C12.2, C13.2, LED1.K (C), R1.1, R2.1, R3.1, R4.1, R5.1, R6.1, R7.1, R8.1, R9.1, R10.1, R11.1, R12.1, SV14.16, U1.1 (GND), U2.1 (GND), U3.1 (GND), U4.1 (GND), U5.1 (GND), U6.1 (GND), U7.1 (GND), U8.1 (GND), U9.1 (GND), U10.1 (GND), U11.1 (GND), U12.1 (GND)
LE: SV14.4, U1.4 (LE), U2.4 (LE), U3.4 (LE), U4.4 (LE), U5.4 (LE), U6.4 (LE), U7.4 (LE), U8.4 (LE), U9.4 (LE), U10.4 (LE), U11.4 (LE), U12.4 (LE)
unnamed: SV1.1, U1.5 (OUT0)
unnamed: SV1.5, U1.9 (OUT4)
unnamed: SV1.3, U1.7 (OUT2)
unnamed: SV1.7, U1.11 (OUT6)
unnamed: SV1.11, U1.15 (OUT10)
unnamed: SV1.13, U1.17 (OUT12)
unnamed: SV1.9, U1.13 (OUT8)
unnamed: SV1.15, U1.19 (OUT14)
unnamed: SV1.2, U1.6 (OUT1)
unnamed: SV1.4, U1.8 (OUT3)
unnamed: SV1.6, U1.10 (OUT5)
unnamed: SV1.8, U1.12 (OUT7)
unnamed: SV1.10, U1.14 (OUT9)
unnamed: SV1.12, U1.16 (OUT11)
unnamed: SV1.14, U1.18 (OUT13)
unnamed: SV1.16, U1.20 (OUT15)
unnamed: SV2.1, U2.5 (OUT0)
unnamed: R1.2, U1.23 (R-EXT)
unnamed: SV2.3, U2.7 (OUT2)
unnamed: SV2.5, U2.9 (OUT4)
unnamed: SV2.7, U2.11 (OUT6)
unnamed: SV2.11, U2.15 (OUT10)
unnamed: SV2.9, U2.13 (OUT8)
unnamed: SV2.13, U2.17 (OUT12)
unnamed: SV2.15, U2.19 (OUT14)
unnamed: SV2.2, U2.6 (OUT1)
unnamed: SV2.4, U2.8 (OUT3)
unnamed: SV2.6, U2.10 (OUT5)
unnamed: SV2.8, U2.12 (OUT7)
unnamed: SV2.10, U2.14 (OUT9)
unnamed: SV2.12, U2.16 (OUT11)
unnamed: SV2.14, U2.18 (OUT13)
unnamed: SV2.16, U2.20 (OUT15)
unnamed: R2.2, U2.23 (R-EXT)
unnamed: SV3.1, U3.5 (OUT0)
unnamed: SV3.3, U3.7 (OUT2)
unnamed: SV3.5, U3.9 (OUT4)
unnamed: SV3.7, U3.11 (OUT6)
unnamed: SV3.11, U3.15 (OUT10)
unnamed: SV3.9, U3.13 (OUT8)
unnamed: SV3.13, U3.17 (OUT12)
unnamed: SV3.15, U3.19 (OUT14)
unnamed: SV3.2, U3.6 (OUT1)
unnamed: SV3.4, U3.8 (OUT3)
unnamed: SV3.6, U3.10 (OUT5)
unnamed: SV3.8, U3.12 (OUT7)
unnamed: SV3.10, U3.14 (OUT9)
unnamed: SV3.12, U3.16 (OUT11)
unnamed: SV3.14, U3.18 (OUT13)
unnamed: SV3.16, U3.20 (OUT15)
unnamed: R3.2, U3.23 (R-EXT)
unnamed: SV4.1, U4.5 (OUT0)
unnamed: SV4.3, U4.7 (OUT2)
unnamed: SV4.5, U4.9 (OUT4)
unnamed: SV4.7, U4.11 (OUT6)
unnamed: SV4.11, U4.15 (OUT10)
unnamed: SV4.9, U4.13 (OUT8)
unnamed: SV4.13, U4.17 (OUT12)
unnamed: SV4.15, U4.19 (OUT14)
unnamed: SV4.2, U4.6 (OUT1)
unnamed: SV4.4, U4.8 (OUT3)
unnamed: SV4.6, U4.10 (OUT5)
unnamed: SV4.8, U4.12 (OUT7)
unnamed: SV4.10, U4.14 (OUT9)
unnamed: SV4.12, U4.16 (OUT11)
unnamed: SV4.14, U4.18 (OUT13)
unnamed: SV4.16, U4.20 (OUT15)
unnamed: R4.2, U4.23 (R-EXT)
unnamed: SV5.1, U5.5 (OUT0)
unnamed: SV5.3, U5.7 (OUT2)
unnamed: SV5.5, U5.9 (OUT4)
unnamed: SV5.7, U5.11 (OUT6)
unnamed: SV5.11, U5.15 (OUT10)
unnamed: SV5.9, U5.13 (OUT8)
unnamed: SV5.13, U5.17 (OUT12)
unnamed: SV5.15, U5.19 (OUT14)
unnamed: SV5.2, U5.6 (OUT1)
unnamed: SV5.4, U5.8 (OUT3)
unnamed: SV5.6, U5.10 (OUT5)
unnamed: SV5.8, U5.12 (OUT7)
unnamed: SV5.10, U5.14 (OUT9)
unnamed: SV5.12, U5.16 (OUT11)
unnamed: SV5.14, U5.18 (OUT13)
unnamed: SV5.16, U5.20 (OUT15)
unnamed: R5.2, U5.23 (R-EXT)
unnamed: SV6.1, U6.5 (OUT0)
unnamed: SV6.3, U6.7 (OUT2)
unnamed: SV6.5, U6.9 (OUT4)
unnamed: SV6.7, U6.11 (OUT6)
unnamed: SV6.11, U6.15 (OUT10)
unnamed: SV6.9, U6.13 (OUT8)
unnamed: SV6.13, U6.17 (OUT12)
unnamed: SV6.15, U6.19 (OUT14)
unnamed: SV6.2, U6.6 (OUT1)
unnamed: SV6.4, U6.8 (OUT3)
unnamed: SV6.6, U6.10 (OUT5)
unnamed: SV6.8, U6.12 (OUT7)
unnamed: SV6.10, U6.14 (OUT9)
unnamed: SV6.12, U6.16 (OUT11)
unnamed: SV6.14, U6.18 (OUT13)
unnamed: SV6.16, U6.20 (OUT15)
unnamed: R6.2, U6.23 (R-EXT)
unnamed: SV7.1, U7.5 (OUT0)
unnamed: SV7.3, U7.7 (OUT2)
unnamed: SV7.5, U7.9 (OUT4)
unnamed: SV7.7, U7.11 (OUT6)
unnamed: SV7.9, U7.13 (OUT8)
unnamed: SV7.13, U7.17 (OUT12)
unnamed: SV7.15, U7.19 (OUT14)
unnamed: SV7.2, U7.6 (OUT1)
unnamed: SV7.4, U7.8 (OUT3)
unnamed: SV7.6, U7.10 (OUT5)
unnamed: SV7.8, U7.12 (OUT7)
unnamed: SV7.10, U7.14 (OUT9)
unnamed: SV7.12, U7.16 (OUT11)
unnamed: SV7.14, U7.18 (OUT13)
unnamed: SV7.16, U7.20 (OUT15)
unnamed: SV7.11, U7.15 (OUT10)
unnamed: R7.2, U7.23 (R-EXT)
unnamed: SV8.1, U8.5 (OUT0)
unnamed: SV8.3, U8.7 (OUT2)
unnamed: SV8.5, U8.9 (OUT4)
unnamed: SV8.7, U8.11 (OUT6)
unnamed: SV8.11, U8.15 (OUT10)
unnamed: SV8.9, U8.13 (OUT8)
unnamed: SV8.13, U8.17 (OUT12)
unnamed: SV8.15, U8.19 (OUT14)
unnamed: SV8.2, U8.6 (OUT1)
unnamed: SV8.4, U8.8 (OUT3)
unnamed: SV8.6, U8.10 (OUT5)
unnamed: SV8.8, U8.12 (OUT7)
unnamed: SV8.10, U8.14 (OUT9)
unnamed: SV8.12, U8.16 (OUT11)
unnamed: SV8.14, U8.18 (OUT13)
unnamed: SV8.16, U8.20 (OUT15)
unnamed: R8.2, U8.23 (R-EXT)
unnamed: SV9.1, U9.5 (OUT0)
unnamed: SV9.3, U9.7 (OUT2)
unnamed: SV9.5, U9.9 (OUT4)
unnamed: SV9.7, U9.11 (OUT6)
unnamed: SV9.11, U9.15 (OUT10)
unnamed: SV9.9, U9.13 (OUT8)
unnamed: SV9.13, U9.17 (OUT12)
unnamed: SV9.15, U9.19 (OUT14)
unnamed: SV9.2, U9.6 (OUT1)
unnamed: SV9.4, U9.8 (OUT3)
unnamed: SV9.6, U9.10 (OUT5)
unnamed: SV9.8, U9.12 (OUT7)
unnamed: SV9.10, U9.14 (OUT9)
unnamed: SV9.12, U9.16 (OUT11)
unnamed: SV9.14, U9.18 (OUT13)
unnamed: SV9.16, U9.20 (OUT15)
unnamed: R9.2, U9.23 (R-EXT)
unnamed: SV10.1, U10.5 (OUT0)
unnamed: SV10.3, U10.7 (OUT2)
unnamed: SV10.5, U10.9 (OUT4)
unnamed: SV10.7, U10.11 (OUT6)
unnamed: SV10.11, U10.15 (OUT10)
unnamed: SV10.9, U10.13 (OUT8)
unnamed: SV10.13, U10.17 (OUT12)
unnamed: SV10.15, U10.19 (OUT14)
unnamed: SV10.2, U10.6 (OUT1)
unnamed: SV10.4, U10.8 (OUT3)
unnamed: SV10.6, U10.10 (OUT5)
unnamed: SV10.8, U10.12 (OUT7)
unnamed: SV10.10, U10.14 (OUT9)
unnamed: SV10.12, U10.16 (OUT11)
unnamed: SV10.14, U10.18 (OUT13)
unnamed: SV10.16, U10.20 (OUT15)
unnamed: R10.2, U10.23 (R-EXT)
unnamed: SV11.1, U11.5 (OUT0)
unnamed: SV11.3, U11.7 (OUT2)
unnamed: SV11.5, U11.9 (OUT4)
unnamed: SV11.7, U11.11 (OUT6)
unnamed: SV11.11, U11.15 (OUT10)
unnamed: SV11.9, U11.13 (OUT8)
unnamed: SV11.13, U11.17 (OUT12)
unnamed: SV11.15, U11.19 (OUT14)
unnamed: SV11.2, U11.6 (OUT1)
unnamed: SV11.4, U11.8 (OUT3)
unnamed: SV11.6, U11.10 (OUT5)
unnamed: SV11.8, U11.12 (OUT7)
unnamed: SV11.10, U11.14 (OUT9)
unnamed: SV11.12, U11.16 (OUT11)
unnamed: SV11.14, U11.18 (OUT13)
unnamed: SV11.16, U11.20 (OUT15)
unnamed: R11.2, U11.23 (R-EXT)
unnamed: SV12.1, U12.5 (OUT0)
unnamed: SV12.3, U12.7 (OUT2)
unnamed: SV12.5, U12.9 (OUT4)
unnamed: SV12.7, U12.11 (OUT6)
unnamed: SV12.11, U12.15 (OUT10)
unnamed: SV12.9, U12.13 (OUT8)
unnamed: SV12.13, U12.17 (OUT12)
unnamed: SV12.15, U12.19 (OUT14)
unnamed: SV12.2, U12.6 (OUT1)
unnamed: SV12.4, U12.8 (OUT3)
unnamed: SV12.6, U12.10 (OUT5)
unnamed: SV12.8, U12.12 (OUT7)
unnamed: SV12.10, U12.14 (OUT9)
unnamed: SV12.12, U12.16 (OUT11)
unnamed: SV12.14, U12.18 (OUT13)
unnamed: SV12.16, U12.20 (OUT15)
unnamed: R12.2, U12.23 (R-EXT)
unnamed: U1.22 (SDO), U2.2 (SDI)
unnamed: U2.22 (SDO), U3.2 (SDI)
unnamed: U3.22 (SDO), U4.2 (SDI)
unnamed: U5.22 (SDO), U6.2 (SDI)
unnamed: U6.22 (SDO), U7.2 (SDI)
unnamed: U7.22 (SDO), U8.2 (SDI)
unnamed: U9.22 (SDO), U10.2 (SDI)
unnamed: U10.22 (SDO), U11.2 (SDI)
unnamed: U11.22 (SDO), U12.2 (SDI)
unnamed: Q1.C, SV13.1
unnamed: Q2.C, SV13.3
unnamed: Q3.C, SV13.5
unnamed: Q4.C, SV13.7
unnamed: Q5.C, SV13.9
unnamed: Q6.C, SV13.11
unnamed: Q1.B, R13.1
unnamed: Q7.C, SV13.13
unnamed: Q8.C, SV13.15
unnamed: Q8.B, R20.1
unnamed: Q7.B, R19.1
unnamed: Q6.B, R18.1
unnamed: Q5.B, R17.1
unnamed: Q4.B, R16.1
unnamed: Q3.B, R15.1
unnamed: Q2.B, R14.1
unnamed: R20.2, SV14.15
unnamed: LED1.A, R22.1
unnamed: R19.2, SV14.13
unnamed: R18.2, SV14.11
unnamed: R17.2, SV14.9
unnamed: R16.2, SV14.7
unnamed: R15.2, SV14.5
unnamed: R14.2, SV14.3
unnamed: R13.2, SV14.1
SDI_B: SV14.12, U9.2 (SDI)
SDI_G: SV14.10, U5.2 (SDI)
SDI_R: SV14.8, U1.2 (SDI)
~OE: SV14.6, U1.21 (~OE), U2.21 (~OE), U3.21 (~OE), U4.21 (~OE), U5.21 (~OE), U6.21 (~OE), U7.21 (~OE), U8.21 (~OE), U9.21 (~OE), U10.21 (~OE), U11.21 (~OE), U12.21 (~OE)

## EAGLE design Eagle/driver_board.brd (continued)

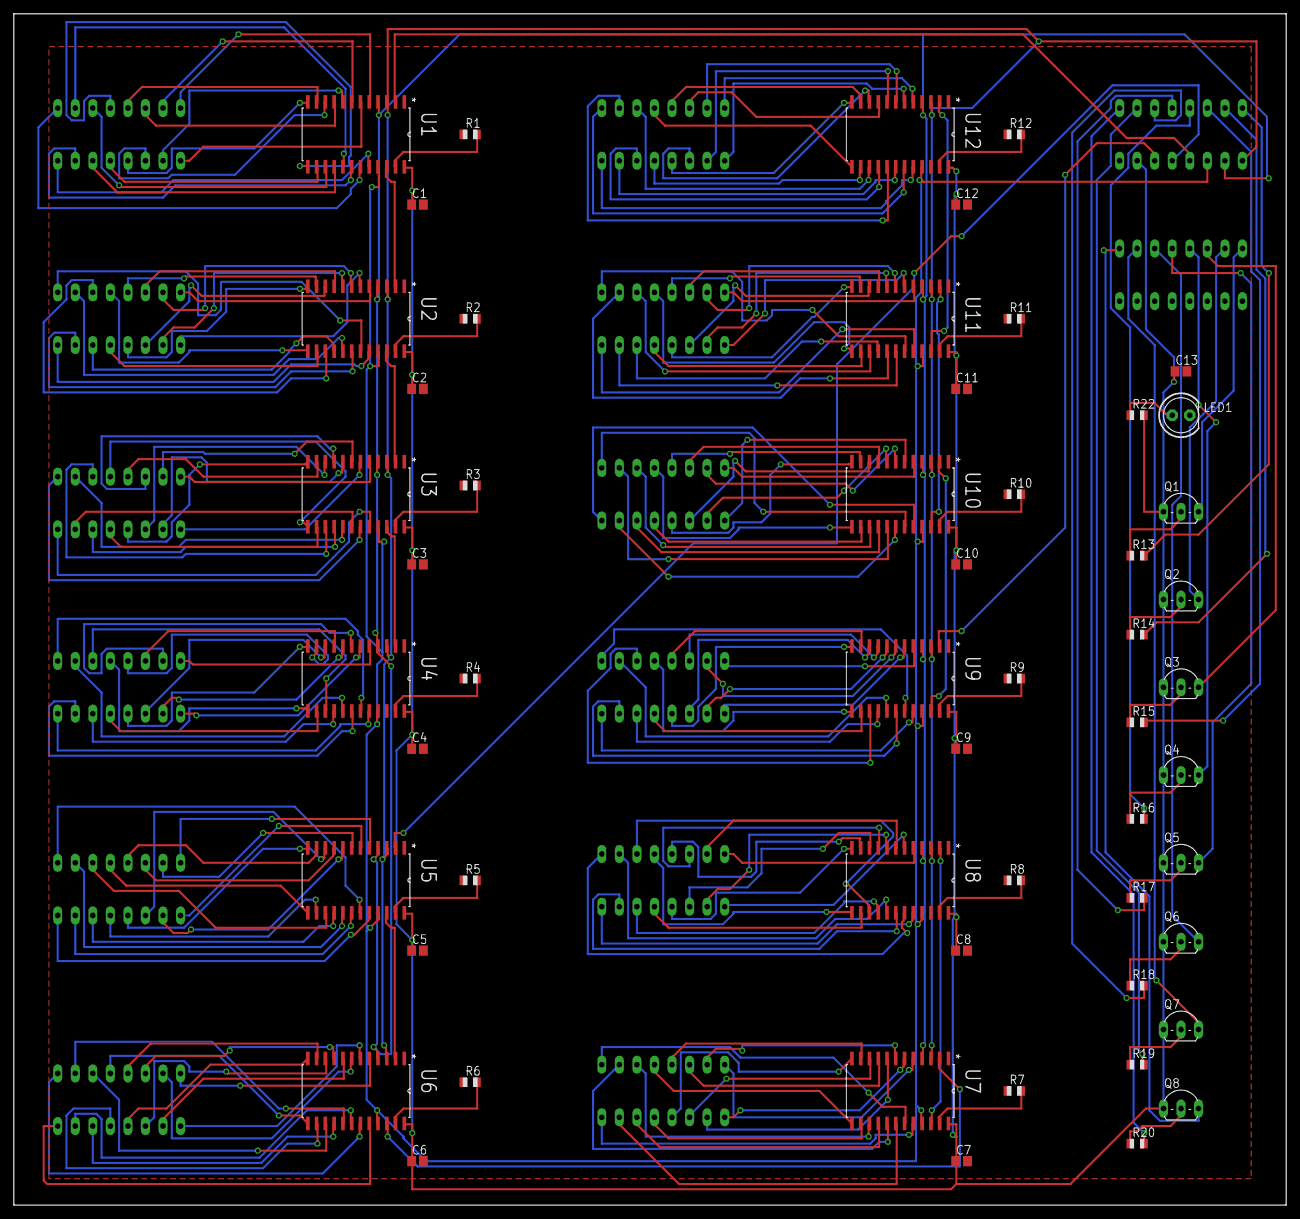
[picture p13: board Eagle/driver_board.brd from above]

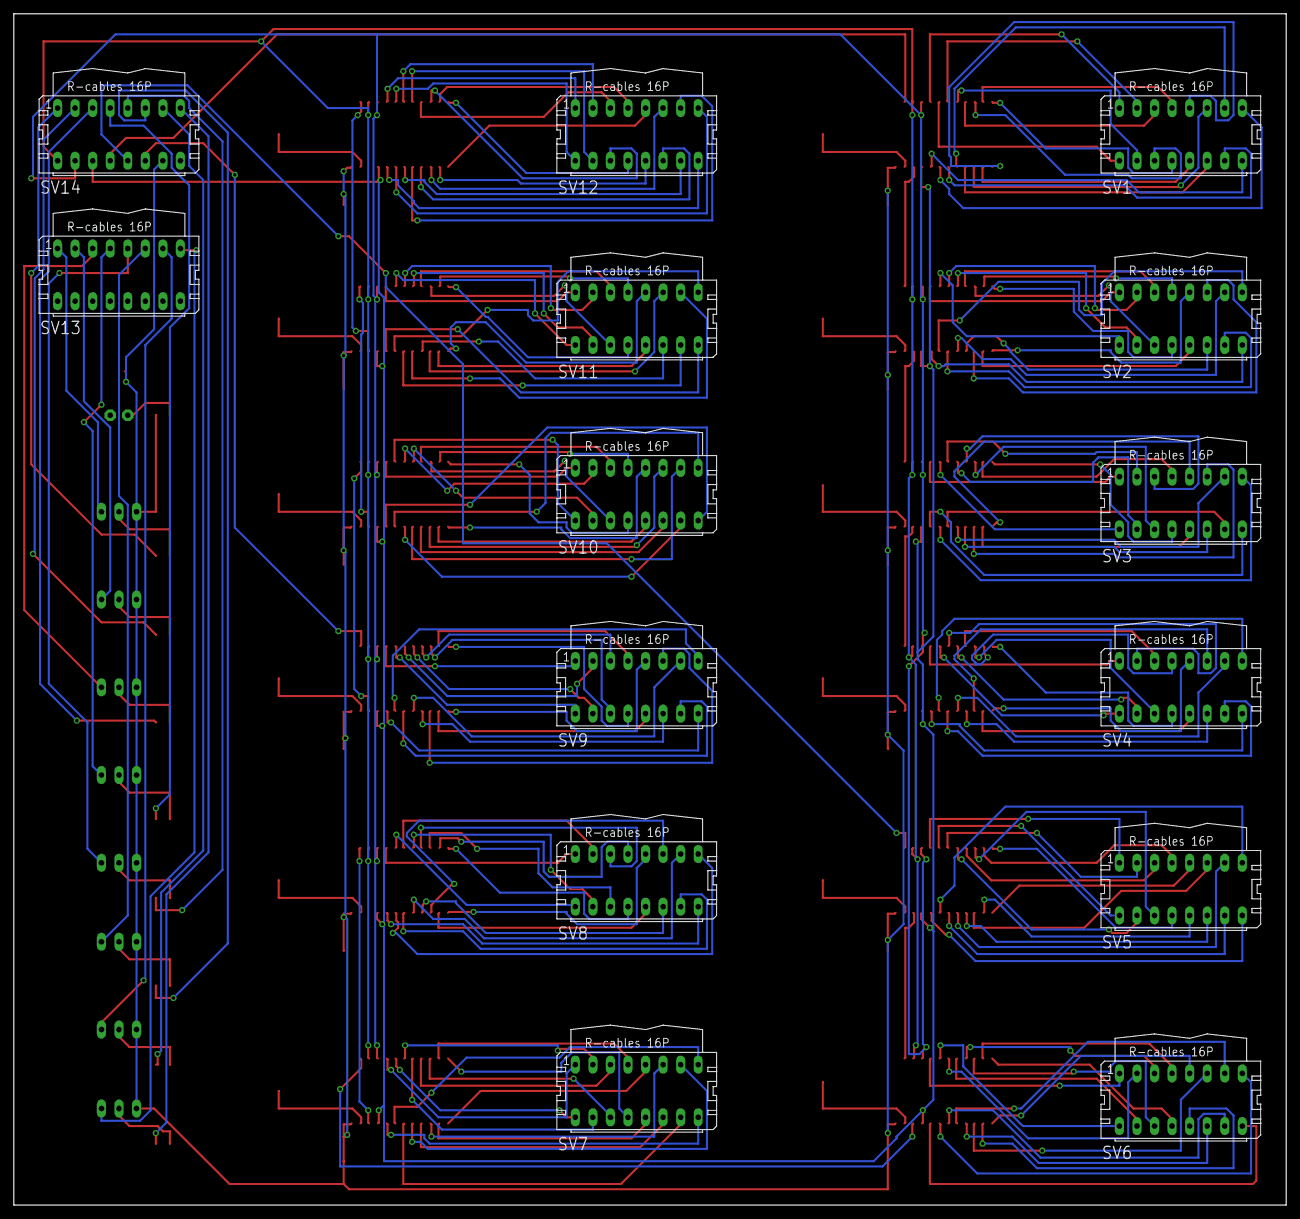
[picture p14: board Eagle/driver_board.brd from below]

Board: 2 copper layers, 184.1 x 172.4 mm, 69 parts (14 on the bottom side), 246 nets.

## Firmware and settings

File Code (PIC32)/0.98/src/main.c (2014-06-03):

#include "../include/main.h"

/*** Pragmas for setting up PIC32 osillator and chip ***/
#pragma config POSCMOD      = HS        // Enable high speed oscillator module
#pragma config FNOSC        = PRIPLL    // use primary PLL
#pragma config FPLLIDIV     = DIV_2     // Divide 8MHz crystal clock by 2 for 4MHz to PLL input
#pragma config FPLLMUL      = MUL_20    // Multiply PLL by 15 (=80MHz)
#pragma config FPLLODIV     = DIV_2     // PLL output divide by 1 (=40MHZ Fcy)
#pragma config FPBDIV       = DIV_1     // Divide core clock by 1 for peripheral bus (=40MHz Fpb)
#pragma config FSOSCEN      = OFF
#pragma config FWDTEN       = OFF       // Disable Watchdog timer
#pragma config FCKSM        = CSDCMD
#pragma config CP           = OFF       // Disable code protect
#pragma config BWP          = OFF       // Disable boot write protect
#pragma config PWP          = OFF       // Disable program write Protect

// some important globals. 
volatile int cubeLayer = 0;
volatile uint16 bcmBitTicNext = 1;
volatile uint16 bcmBitTic = 1;
volatile uint16 bcmBitPos = 0;
volatile uint16 bcmBit = 0;
volatile uint32 fRateLast, rRateLast;
volatile struct animNode_t *head = NULL;
volatile struct animNode_t *curr = NULL;
volatile counter_t frmCtr;
volatile counter_t rgbCtr;
uint16 anIndex = 0;
unsigned long g_msCounter;
rgb_t g_colorBuffer[8][8][8];
anim_t anims[64] = { NULL };
anim_t *ptrAnim = NULL;

/*
===================
 Name

 Desc
===================
*/
void __ISR ( _TIMER_2_VECTOR, ipl1 ) TMR2IntHandler( void ) {
 //   mT4IntEnable(0);
    int16 x, y;
    LATBSET = INT_T2_TEST_PIN;   

     /* BCM stuff
     * 4 bits of color resolution (3375 colors) seems to work best at 40 Mhz
     * Adding the 5th bit results in a delay which causes noticeable flickering
     * due to the time spent processing a single layer. Still works better than
     * the previous versions, and with better accuracy. Might try to bum in a
     * 5th bit at some point just for the sake of doing so but not worth the
     * time right now. I also added some stuff elsewhere to automatically compensate for
     * color depths lower than 8 bits without having to rewrite the RGB color
     * handling logic for each possible case.
     */
    // bcmBitPos = [0...7]
    // When all BCM bits have been processed for this layer, move to the next one
    if ( bcmBitPos > CUBE_BCM_BITS ) {
        LATECLR = LAYER_ALL_Q;  // turn off all layer transistors
        // Increment the current layer of the cube.
        if ( cubeLayer++ > CUBE_Z_MAX ) {
            cubeLayer = 0;
        }
        // reset all when we've moved up one on the z-axis
        bcmBitPos = 0;
        bcmBitTic = 1;
        bcmBitTicNext = 1;
    }

    // set the current color weight bit to be evaluated from the frame buffer
    bcmBit = 1 << bcmBitPos;

    // if current BCM period is complete...
    if ( bcmBitTic == bcmBitTicNext ) {       
        // reset tick
        bcmBitTic = 1;
        // increment current BCM bit position
        bcmBitPos++;
        // double the next BCM tick count (period)
        bcmBitTicNext <<= 1;        

    } else {
        // otherwise, increment the tick count
        bcmBitTic++;
    }

    for ( y = CUBE_Y_MAX; y >= 0; y-- ) {
        for ( x = CUBE_X_MAX; x >= 0; x-- ) {
            // X-coord LEDs on odd-numbered Y-offsets are wired backwards (doh).
            // So this quick hack reverses the shift order on the X-axis on odd-numbered y-axes
            // This block can be removed if/when I ever correct the wiring
           if ( y % 2 != 0 ) {
               // calculate modified x-offset once to save a little time when indexing
                int _x = ( 7-x ); 

                if ( g_frameBuffer[_x][y][cubeLayer].r & bcmBit )
                    LATBSET = SR_SDI_R;

                if ( g_frameBuffer[_x][y][cubeLayer].g & bcmBit )
                    LATBSET = SR_SDI_G;

                if ( g_frameBuffer[_x][y][cubeLayer].b & bcmBit )
                    LATBSET = SR_SDI_B;                           
            } else {
                // If we're on an even-numbered Y-offset, shift the data normally.
                if ( g_frameBuffer[x][y][cubeLayer].r & bcmBit )
                    LATBSET = SR_SDI_R;

                if ( g_frameBuffer[x][y][cubeLayer].g & bcmBit )
                    LATBSET = SR_SDI_G;

                if ( g_frameBuffer[x][y][cubeLayer].b & bcmBit )
                    LATBSET = SR_SDI_B;
            }

            LATBSET = SR_CLK;
            LATBCLR = SR_CLK | SR_SDI_R | SR_SDI_G | SR_SDI_B;
        } // X axis
    } // Y axis
    //  asm volatile ("ei");
  
    int i;
    switch ( cubeLayer ) {
        case ( 0 ) :
//            LATBSET = SR_OE;
            for ( i = 0; i < Q_DELAY; i++ ) {
                Nop();
            }
            LATESET = LAYER_Q0;
            LATBSET = SR_LE;
            LATBCLR = SR_LE | SR_OE;
             break;
        case ( 1 ) :
 //           LATBSET = SR_OE;
            for ( i = 0; i < Q_DELAY; i++ ) {
                Nop();
            }
            LATESET = LAYER_Q1;
            LATBSET = SR_LE;
            LATBCLR = SR_LE | SR_OE;
             break;
        case ( 2 ) :
  //          LATBSET = SR_OE;
            for ( i = 0; i < Q_DELAY; i++ ) {
                Nop();
            }
            LATESET = LAYER_Q2;
            LATBSET = SR_LE;
            LATBCLR = SR_LE | SR_OE;
             break;
        case ( 3 ) :
 //           LATBSET = SR_OE;
            for ( i = 0; i < Q_DELAY; i++ ) {
                Nop();
            }
            LATESET = LAYER_Q3;
            LATBSET = SR_LE;
            LATBCLR = SR_LE | SR_OE;
             break;
        case ( 4 ) :
  //          LATBSET = SR_OE;
            for ( i = 0; i < Q_DELAY; i++ ) {
                Nop();
            }
            LATESET = LAYER_Q4;
            LATBSET = SR_LE;
            LATBCLR = SR_LE | SR_OE;
            break;
        case ( 5 ) :
 //           LATBSET = SR_OE;
            for ( i = 0; i < Q_DELAY; i++ ) {
                Nop();
            }
            LATESET = LAYER_Q5;
            LATBSET = SR_LE;
            LATBCLR = SR_LE | SR_OE;
            break;
        case ( 6 ) :
 //           LATBSET = SR_OE;
            for ( i = 0; i < Q_DELAY; i++ ) {
                Nop();
            }
            LATESET = LAYER_Q6;
            LATBSET = SR_LE;
            LATBCLR = SR_LE | SR_OE;
            break;
        case ( 7 ) :
  //          LATBSET = SR_OE;
            for ( i = 0; i < Q_DELAY; i++ ) {
                Nop();
            }
            LATESET = LAYER_Q7;
            LATBSET = SR_LE;
            LATBCLR = SR_LE | SR_OE;
            break;
        default:
            break;
    } // layer switch

    LATBCLR = INT_T2_TEST_PIN;
    mT2ClearIntFlag();
    mT4IntEnable( 1 );
    
} // End Timer2 interrupt

/*
===================
 Name

 Desc
===================
*/

void __ISR( _UART1_VECTOR, ipl2 ) IntUART1Handler( void ) {
    // on rx interrupt, read in the byte and build up the packet as required
    // TODO: store incoming bytes in circular buffer
    if ( mU1RXGetIntFlag() ) {
        // handle message immediately
        L_ReadByte();
        if ( uartBytesRead == 6 ) {
            // prevent T4 counter windups while handling message
            mT4IntEnable( 0 );
            L_MsgHandler( lcdReadBuffer );
            mT4IntEnable( 1 );
        }
        mU1RXClearIntFlag();
    }

    // Don't care about tx interrupt, return immediately
    if ( mU1TXGetIntFlag() ) {
        mU1TXClearIntFlag();
    }
    
} // end UART1 interrupt

/*
===================
 Name

 Desc
===================
*/
void __ISR ( _TIMER_4_VECTOR, ipl3 ) TMR4IntHandler( void ) {
    LATBSET = INT_T4_TEST_PIN;
    g_msCounter++;

    // Update SA peak detect counter
    if ( saPeakCtr.en  ) {
        if ( !saPeakCtr.dn ) {
            if ( ++saPeakCtr.acc == saPeakCtr.pre ) {
                saPeakCtr.dn = 1;
            }
        } else {
            saPeakCtr.acc = 0;
        }
    }

    // recalculate frame rate & rgb fade rate delay on change
    // if USE_GLOBAL flag is set, use rates from global options struct
    if ( TSTFLAG( xsig.AFLAGS, ANIM_USE_GLOBAL ) ) {
        if ( fRateLast != xsig.fRate ) {
            frmCtr.pre = 20000 / xsig.fRate;
            frmCtr.acc = 0;
            fRateLast = xsig.fRate;
        }

        if ( rRateLast != xsig.rRate ) {
            rgbCtr.pre = 20000 / xsig.rRate;
            rgbCtr.acc = 0;
            rRateLast = xsig.rRate;
        }
    // if USE_GLOBAL flag not set, use rates from this animation's options struct
    } else {
        if ( fRateLast != ptrAnim->rate ) {
            frmCtr.pre = 20000 / ptrAnim->rate;
            frmCtr.acc = 0;
            fRateLast = ptrAnim->rate;
        }

        if ( rRateLast != ptrAnim->rgbOpts.rate ) {
            rgbCtr.pre = 20000 / ptrAnim->rgbOpts.rate;
            rgbCtr.acc = 0;
            rRateLast = ptrAnim->rgbOpts.rate;
        }
    }

     // Update animation delay counter
    if ( frmCtr.en ) {
        if ( !frmCtr.dn ) {
            if ( ++frmCtr.acc == frmCtr.pre ) {
                frmCtr.dn = 1;
                frmCtr.acc = 0;
            }
        }
    }

    // Update RGB fade delay counter
    if ( rgbCtr.en ) {
        if ( !rgbCtr.dn ) {
            if ( ++rgbCtr.acc == rgbCtr.pre ) {
                rgbCtr.dn = 1;               
            }
        }

        // check RGB fade delay counter
        if ( rgbCtr.dn ) {
            if ( ++ptrAnim->rgbOpts.angle >= 360 ) {
                ptrAnim->rgbOpts.angle = 0;
            }
            rgbCtr.dn = 0;
            rgbCtr.acc = 0;
        }
    }

    // Get ADC samples for spectrum analyzer animation
    // Don't waste time doing this unless we're running this
    // animation
    if (ptrAnim->id == AN_SA) {
        S_GetADCSamples();
    } 

    LATBCLR = INT_T4_TEST_PIN;
    mT4ClearIntFlag();
} // End Timer4 interrupt

int main() {
    // Configure initial animation list
    I_InitAnim();
    // Configure general settings for chip
    I_InitConfig();
    // Configure LCP setup parameters
    I_InitLCD();
    // Launch main animation loop
    A_Animate();

    return ( EXIT_SUCCESS );
}   // End main

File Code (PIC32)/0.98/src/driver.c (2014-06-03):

#include "../include/driver.h"

rgb_t g_frameBuffer[8][8][8];
extern unsigned long g_msCounter;

/*
===================
 Name

 Desc
===================
*/
void D_TestUART(void){
    char filename[50] ;                         //Array of 50 chars
    memset(filename, 0, 50*sizeof(char));         //Clears the Array
    sprintf(filename, "Testing");               //Places the String into the Array
    putsUART1(filename);                        //Sends the Array over UART1

    int variable=0;
    int index=0;

    while (1) {
        sprintf(filename, "%d\n",variable); //%d will get the value of the next argument in the function and place it in the string
        putsUART1(filename);                //Sends the Array over UART1
        variable++;                         //Increments the variable by 1

        for(index=0; index < 4000000; index++) //a dummy function ot delay the loop
            Nop(); // no operation for this cycle
    }
}

/*
===================
 Name

 Desc
===================
*/
long D_SetCtrmS(float in_ms) {
    // T4 interrupt is 1 tick/50uS -> 20 ticks / 1 mS
    return in_ms * 20;
}

/*
===================
 Name

 Desc
===================
*/
bool D_Delayms( float ms ) {
    long delay;
    static long count, tmp = 0;

    delay = ms;// * 20;

    if (g_msCounter != tmp) {
        tmp = g_msCounter;
        count++;
    }

    if (count >= delay) {
        count = 0;
        tmp = 0;
        return 1;
    }
    
    else
        return 0;

}

/*
===================
 D_Dist2D

 Returns euclidian distance between two points on 2D plane surface
===================
*/
float D_Dist2D( float x1,  float y1, float x2, float y2 ) {
  float dist;
  dist = sqrt( ( x1-x2 )*( x1-x2 ) + ( y1-y2 )*( y1-y2 ) );

  return dist;
}

/*
===================
 D_Dist3D

 Returns euclidian distance between two points within cube
===================
*/
D_Dist3D( float x1,  float y1, float z1, float x2, float y2, float z2 ) {
  float dist;
  dist = sqrt( ( x1-x2 )*( x1-x2 ) + ( y1-y2 )*( y1-y2 ) + ( z1-z2 )*( z1-z2 ) );

  return dist;
}



/*
===================
 D_Abs

 Returns absolute value of input
===================
*/
float D_Abs( float in ) {
    return (in > 0 ? in : -in);
}

/*
===================
 Name

 Desc
===================
*/
int32 D_Round( float in ) {
    int16 s = in / D_Abs( in );
    return (int16)(s * ( D_Abs( in ) + 0.5 ) );
}

/*
===================
 Name

 Desc
===================
*/
bool D_Bounds( int x, int y, int z ) {
    if (x >= 0 && x <= CUBE_X_MAX &&
        y >= 0 && y <= CUBE_Y_MAX &&
        z >= 0 && z <= CUBE_Z_MAX)
        return TRUE;    
    else
        return FALSE;
}

/*
===================
 Name

 Desc
===================
*/
float D_Remap( float in, float inMin, float inMax, float outMin, float outMax ) {
	float out;
	out = ( in - inMin ) / ( inMax - inMin ) * ( outMax - outMin ) + outMin;
	return out;
}

/*
===================
 Name

 Desc
===================
*/
struct animNode_t* D_ListCreate( anim_t anim ) {
    struct animNode_t *ptr = ( struct animNode_t* ) malloc ( sizeof(struct animNode_t) );
    if ( ptr == NULL ) {
        printf("\n Node creation failed \n");
        return NULL;
    }
    ptr->anim = anim;
    ptr->next = NULL;

    head = curr = ptr;
    return ptr;
}

/*
===================
 Name

 Desc
===================
*/
struct animNode_t* D_ListAddAnim( anim_t anim, bool addEnd ) {

}

/*
===================
 Name

 Desc
===================
*/
int D_ListDeleteAnim( anim_t anim ) {
    struct animNode_t *prev = NULL;
    struct animNode_t *del = NULL;

    del = D_ListSearchAnim( anim, &prev );
    if( del == NULL ) {
        return -1;
    } else {
        if(prev != NULL) {
            prev->next = del->next;
        }
        if(del == curr) {
            curr = prev;
        }   else if( del == head ) {
            head = del->next;
        }
    }

    free( del );
    del = NULL;

    return 0;
}

/*
===================
 Name

 Desc
===================
*/
struct animNode_t* D_ListSearchAnim( anim_t anim, struct animNode_t **prev ) {

}

/*
===================
 Name

 Desc
===================
*/
void D_Line( uint8 x1, uint8 y1, uint8 z1, uint8 x2, uint8 y2, uint8 z2, rgb_t rgb ) {
    int i, dx, dy, dz, l, m, n;
    int x_inc, y_inc, z_inc, err_1, err_2, dx2, dy2, dz2;
    uint8 point[3];

    point[0] = x1;
    point[1] = y1;
    point[2] = z1;
    dx = x2 - x1;
    dy = y2 - y1;
    dz = z2 - z1;
    x_inc = (dx < 0) ? -1 : 1;
    l = abs(dx);
    y_inc = (dy < 0) ? -1 : 1;
    m = abs(dy);
    z_inc = (dz < 0) ? -1 : 1;
    n = abs(dz);
    dx2 = l << 1;
    dy2 = m << 1;
    dz2 = n << 1;

    if ((l >= m) && (l >= n)) {
        err_1 = dy2 - l;
        err_2 = dz2 - l;
        
        for (i = 0; i < l; i++) {
            V_Set(point[0], point[1], point[2], rgb);
            if (err_1 > 0) {
                point[1] += y_inc;
                err_1 -= dx2;
            }
            if (err_2 > 0) {
                point[2] += z_inc;
                err_2 -= dx2;
            }
            err_1 += dy2;
            err_2 += dz2;
            point[0] += x_inc;
        }
    }
    else if ((m >= 1) && (m >= n)) {
        err_1 = dx2 - m;
        err_2 = dz2 - m;

        for (i = 0; i < m; i++) {
            V_Set(point[0], point[1], point[2], rgb);
            if (err_1 > 0) {
                point[0] += x_inc;
                err_1 -= dy2;
            }
            if (err_2 > 0) {
                point[2] += z_inc;
                err_2 -= dy2;
            }
            err_1 += dx2;
            err_2 += dz2;
            point[1] += y_inc;
        }
    }
    else {
        err_1 = dy2 - n;
        err_2 = dx2 - n;
        
        for (i = 0; i < n; i++) {
            V_Set(point[0], point[1], point[2], rgb);
            if (err_1 > 0) {
                point[1] += y_inc;
                err_1 -= dz2;
            }
            if (err_2 > 0) {
                point[0] += x_inc;
                err_2 -= dz2;
            }
            err_1 += dy2;
            err_2 += dx2;
            point[2] += z_inc;
        }
    }
    
    V_Set(point[0], point[1], point[2], rgb);
}

/*
===================
 Name

 Desc
===================
*/
void D_Rect( uint8* center_pt, const char *plane, uint8 vox_l, uint8 vox_w ) {
    if (!(strcmp(plane, "XY"))) {
    }

    if (!(strcmp(plane, "XZ"))) {
    }

    if (!(strcmp(plane, "YZ"))) {
    }

}

/*
===================
 Name

 Desc
===================
*/
void D_Cube( void ) {
// Idea: draw rectangle and stretch it by translation?

}

/*
===================
 Name

 Desc
===================
*/
void D_Circle( uint8 rad, uint8 xc, uint8 yc, uint8 cz ) {
    // float x, y, z;
    uint8 x, y, z;
    float t;

    for (t = 0; t <= TWO_PI; t += 0.1) {
        x = D_Round(rad * cos(t));
        x = x + xc;

        y = D_Round(rad * sin(t));
        y = y + yc;

   //     vxSet(x, y, 3, rgbGetColorCoord(x, y, 3));
    }
}
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

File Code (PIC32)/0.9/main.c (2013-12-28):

#include "main.h"

/*** Pragmas for setting up PIC32 osillator and chip ***/
#pragma config POSCMOD      = HS        // Enable high speed osillator module
#pragma config FNOSC        = PRIPLL    // use primary PLL
#pragma config FPLLIDIV     = DIV_2     // Divide 8MHz crystal clock by 2 for 4MHz to PLL input
#pragma config FPLLMUL      = MUL_20    // Multiply PLL by 15 (=80MHz)
#pragma config FPLLODIV     = DIV_1     // PLL output divide by 1 (=80MHZ Fcy)
#pragma config FPBDIV       = DIV_8     // Divide core clock by 2 for peripheral bus (=20MHz Fpb)
#pragma config FWDTEN       = OFF       // Disable Watchdog timer
#pragma config CP           = OFF       // Disable code protect
#pragma config BWP          = OFF       // Disable boot write protect
#pragma config PWP          = OFF       // Program program write Protect

// Globals
volatile uint8 rgb_buff_full = 0;
volatile uint8 cube_layer = 0;
volatile uint16 bcm_bit_tick = 0;
volatile uint16 next_bcm_bit_tick = 1;
volatile uint8 bcm_bit_pos = 0;
int test_ctr = 0;

void __ISR (_TIMER_2_VECTOR, ipl2) TMR2IntHandler(void) {
    int8 x, y, z;
    z = cube_layer;
    
    // Working
    for (y = Y_MAX; y >= 0; y--) {
        for (x = X_MAX; x >= 0; x--) {
            // Odd-numbered Y-offsets are wired backwards (due to my own impatience).
            // Need to reverse the shift order on the X-axis in this case.
            // Remove the (7-x) X-offset hack if/when the wiring is corrected.
            if ((y % 2) != 0) {
                if ((g_cube_fb[(7-x)][y][z].r >> bcm_bit_pos))
                    LATBSET = SR_SDI_R;

                if ((g_cube_fb[(7-x)][y][z].g >> bcm_bit_pos))
                    LATBSET = SR_SDI_G;

                if ((g_cube_fb[(7-x)][y][z].b >> bcm_bit_pos))
                    LATBSET = SR_SDI_B;
            }
            // If we're on an even-numbered Y-offset, shift the data normally.
            else {
                if ((g_cube_fb[x][y][z].r >> bcm_bit_pos))
                    LATBSET = SR_SDI_R;

                if ((g_cube_fb[x][y][z].g >> bcm_bit_pos))
                    LATBSET = SR_SDI_G;

                if ((g_cube_fb[x][y][z].b >> bcm_bit_pos))
                    LATBSET = SR_SDI_B;
            }

            // Send current voxel color data to SRs
            LATBSET = SR_CLK;
            LATBCLR = SR_CLK | SR_SDI_R | SR_SDI_G | SR_SDI_B;
            } // X axis
    } // Y axis

      // Turn on the current layer und blinken ze lights
      /* Note: The short delay in between each layer switch is to ensure
       * that the PIC32 has fully transitioned the PORT outputs. Without the delay,
       * I've noticed the layer transistor previously ON appears to still conduct slightly
       * resulting in unwanted albeit very dim lighting of the previous layer.
       * Probably due to the transistors I used not being able to tolerate the
       * extremely fast port switching speed.
       */
    uint16 i;
    switch (cube_layer) {
        case (0) :
            LATESET = LAYER_Q7;
            for (i = 0; i < Q_DELAY; i++) {}
            LATECLR = LAYER_Q0;
             break;
        case (1) :
            LATESET = LAYER_Q0;
            for (i = 0; i < Q_DELAY; i++) {}
            LATECLR = LAYER_Q1;
             break;
        case (2) :
            LATESET = LAYER_Q1;
            for (i = 0; i < Q_DELAY; i++) {}
            LATECLR = LAYER_Q2;
             break;
        case (3) :
            LATESET = LAYER_Q2;
            for (i = 0; i < Q_DELAY; i++) {}
            LATECLR = LAYER_Q3;
             break;
        case (4) :
            LATESET = LAYER_Q3;
            for (i = 0; i < Q_DELAY; i++) {}
            LATECLR = LAYER_Q4;
            break;
        case (5) :
            LATESET = LAYER_Q4;
            for (i = 0; i < Q_DELAY; i++) {}
            LATECLR = LAYER_Q5;
            break;
        case (6) :
            LATESET = LAYER_Q5;
            for (i = 0; i < Q_DELAY; i++) {}
            LATECLR = LAYER_Q6;
            break;
        case (7) :
            LATESET = LAYER_Q6;
            for (i = 0; i < Q_DELAY; i++) {}
            LATECLR = LAYER_Q7;
            break;
        default:
            break;
    } // layer switch

   // Latch SR outputs
    LATBSET = SR_LE;
    LATBCLR = SR_LE;
        
    // Layer refresh complete. Increment layer num for next interrupt and return
    if (cube_layer < Z_MAX)
        cube_layer++;
    else
        cube_layer = 0;

     /* Handle BCM stuff before returning from interrupt */
     bcm_bit_tick++;

    // in BCM operation, next_bit_tick corresponds to the (n)th cycle of the refresh period. The value is updated once
    // TMR0 has accumulated the corresponding number of ticks (2^(nth) counts) for this cycle.
    if (bcm_bit_tick == next_bcm_bit_tick) {
            next_bcm_bit_tick <<=  1;
            bcm_bit_pos++;
    }

    // Reset all once refresh period is complete (8 full cycles processed)
    if (bcm_bit_pos == BCM_BIT_MAX) {
            bcm_bit_tick = 0;
            bcm_bit_pos = 0;
            next_bcm_bit_tick = 1;
    }

    mT2ClearIntFlag();
}

// For use with millisecond tick counter
void __ISR (_TIMER_4_VECTOR, ipl3) TMR4IntHandler(void) {
    g_ms_ctr = g_ms_ctr++;
    mT4ClearIntFlag();
}

int main() {
    uint8 anim_ctr;
    // Performance optimization macro
    SYSTEMConfig(SYS_FREQ, SYS_CFG_WAIT_STATES | SYS_CFG_PCACHE);
    TRISB = 0x0000;         // Set all port pins to OUTPUT.
    TRISE = 0x0000;         // Set all port pins to OUTPUT.
    DDPCONbits.JTAGEN = 0;  // Disable JTAG port
    // Timer 2 used for main display refresh interrupt
    OpenTimer2(T2_ON | T2_SOURCE_INT | T2_PS_1_1, T2_INT_PER); 
    ConfigIntTimer2( T2_INT_ON | T2_INT_PRIOR_2);
    // Timer 4 used for general timing
    OpenTimer4(T4_ON | T4_SOURCE_INT | T4_PS_1_64, 50);
    ConfigIntTimer4( T4_INT_ON | T4_INT_PRIOR_3);
    INTEnableSystemMultiVectoredInt();
    // Start with all layer transistors ON (disable all layers)
    LATESET = LAYER_Q0 | LAYER_Q1 | LAYER_Q2 | LAYER_Q3 | LAYER_Q4 |
            LAYER_Q6 | LAYER_Q7;
    // Clear all signals on PORTB on startup
    LATBCLR = SR_OE | SR_LE | SR_CLK | SR_SDI_R | SR_SDI_G | SR_SDI_B;

    while (1) {
    // ** FUTURE - randomize animations at runtime ** //
        
        Animate(SINE_2D, 500);
        Animate(SINE_3D, 500);
        Animate(RAIN, 500);
        Animate(CUBE_FILL_DAZ, 1);
        Animate(TEXT_FLY, 1);


//        Animate(TEST);        // for testing only
       
     } // main loop
    
    return (EXIT_SUCCESS);
}

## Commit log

2013-10-29 Driver Board Commit
    Initial Commit of Driver Board (rev0)
    [driver_board.brd, driver_board.sch]
2013-11-01 Revert "Driver Board Commit"
    This reverts commit d0ab9ee2da23c5bfc241576f39f64d58649d03a1.
    [driver_board.brd, driver_board.sch]
2013-11-01 Driver Board - Final Design Draft
    [driver_board.brd, driver_board.sch]
2013-11-04 Driver Board - Production Release
    final board layout - release for production
    [driver_board.brd, driver_board.sch]
2013-12-01 Test Build - 0.5
    Source Commit - Basic functionality and hardware testing complete. Two
    basic animations tested and functional.
    TODO: BCM bugfixes, timer stuff, color fill stuff
    [driver.c, main.c]
2013-12-06 Test Build 0.8
    Core functionality tested and debugged with some major additions.
    Currently stable and working to satisfaction, more minor tweaks being
    done here and there. BCM, core color fading, and basic animation code
    completed.
    TODO: Complete and test more animations, improve color fade handling and
    mode settings
2013-12-09 Build 0.85
    Additional improvements to color fading code. Currently 4 working
    animations. TODO: more animations, further tweak and improve color
    fading modes and operation.
2014-05-28 Build 0.95
    1. Completely revised and organized code structure and layout
    2. Added LCD interface
    3. Added spectrum analyzer (still WIP - works well but needs a little
    tuning)
    4. Added a few new animations
    [driver_board.brd, driver_board.sch]
2014-06-03 Build 0.98
    1. Further improvements to code organization and structure
    2. Several changes to include new LCD touch screen functionality and
    flow control
    3. Bug fixes for various animations
    4. Timing tweaks (still a little work to do here to unify timings)
    [driver.c, init.c, init.h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]
